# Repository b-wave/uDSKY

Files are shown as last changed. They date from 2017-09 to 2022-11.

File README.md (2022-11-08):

 
# uDSKY PROJECT
## A Physical implementaion of an Apollo AGC DSKY. 
*...with USB 2.0 Connectivity for PC simulators*

This assembly and firmware has sucessfully been used to control both
John Pultorak's Block1 Simulator vers 1.16 in C++ and Ronald Burkey's
Block 2 AGC simulators on <http://www.ibiblio.org/apollo/> 
Further, the Simulation runs great on Raspberry Pi.  I forked the 
files needed for both simulators. <https://github.com/b-wave/virtualagc> 

I mainly run it on a Rapsberry PI with the intention of embedding the Pi in this chassis. I started a 
python script that will run the software so I don't have to start the virtual AGC program.... 
now that is a *work in progress...stay tuned* 

The Teensy 3.2 used in this has a plug in board that contains a Real time clock and navigation sensors.
<https://www.pjrc.com/store/prop_shield.html>  Which will mount to the board nicely.  I also included a couple of Apollo-themed Processing PDEs in <https://github.com/b-wave/uDSKY/tree/master/uDSKY%20IMU>
that work with this board and it can mount to the uDSKY using stacking header pins. 

Why on earth did I do this project?  Ultimately, it is a clock. I intend to have a standalone
version to do navigation demonstation experiments and become a "moon clock" to track
the current position, phase, and distance to the moon - *...in real time!*

### What it is not... 
Its not to scale or even a 1:1 scale model of a DSKY.  How I arrived at the scaling was 
I took the best head-on photo of a DSKY I could find and scaled it to match the 
smallest descrete LED 7-segment *green-ish* displays I could find.
It turned out that at that scale, the Keys were  ~.75" on center, which was nice
eand almost exactly 0.75" Square. Also by happy accident the Teensey fits between the top LED
Displays. The front panel measurments was about 7.0" x 6.5" so about, but
not exactly, half the size of a real DSKY. You will see some early refernces to **mini-DSKY** 
Which is the same thing as **uDSKY**.  The whole thing sandwiches nicely together
using plexiglas plates - which I will provide laser cut patterns for - and #4 AWG hardware spacers.

The **uDSKY** assembly is remarkably sturdy and even kind of hefty too.  The keys and circuit 
boards were attached by small torx head "thread rolling" screws for plastic.  
The Torx heads allow for close proximity to components and I think a little easier to install straight.
The hardware I used were surplus and about 2 AWG, ( for a 1/16" pilot hole) and 1/8" long.  
I got them on e-bay and i don't have the link, there were 100's of them in a box for a few dollars. 
They should be easy to find. I'll update a link if I find a good supplier again. 

There are two other circuit boards I am developing.  The INDICATOR boards for the LEDs
since I used perf boards for this prototype.  The POWER REGULATOR board for stand alone
operation on 12V dc, and illuminating and controlling the VERB, NOUN, and PROG LEDs
and the keyboard backlighting. Since these are a lot of LEDs involved 12V is used for them. 
These will be controlled the same as the other LEDs using two of the non used DP signals
but thru an isolator to control 12V to theses diodes. I also have an idea to use LEDs
and some clear plexiglas to simulate the long EL strips between the three registers - 
 but this is still in the *idea phase*...but the testing is showing promise. 

uDSKY in action 9/20/19 on the 50th moonlanding, running on rPI and ran the *actual* Apollo 11 software (C055), mostly P00 for the entire duration of the flight.   This .gif was when they would have been in lunar orbit at 100hrs 38mins or so MET. 

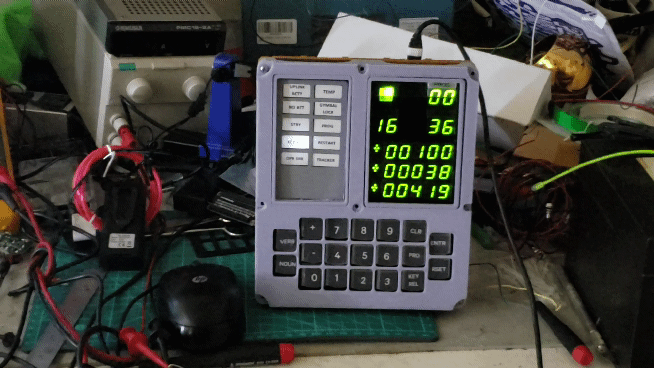
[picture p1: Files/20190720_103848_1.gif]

Running Apollo 11 CMD Module Software. 

The circuit boards are mostly attached to a 1/8" plexiglas rear plate.  The Teensey is
mounted on female pin headers on the main display board.  The Teensy actully slips thru
a recetangular hole in the rear mounting plate. 

## Displays
The displays are multiplexed with the DP segments from the first two controlling the LED INDICATORS.  Each lamp is controlled by the decimal point signals, which were not used in the original Apollo DSKY display.  This turned out to be a good parts reduction
as all the segments and Indicators can be controlle by only 3 LED controller chips.

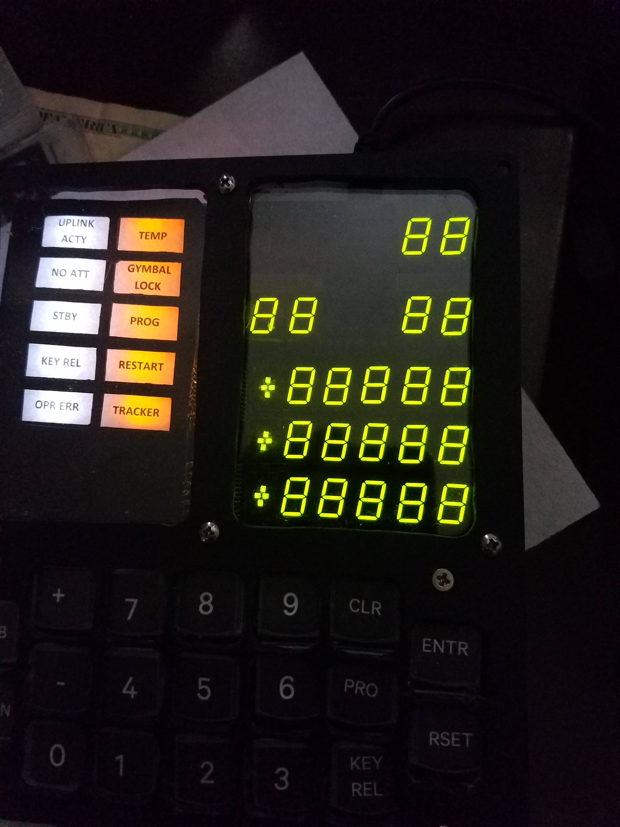
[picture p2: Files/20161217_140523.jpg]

All Displays are ON!

Only the SEGMENT G and DP are used in the first display for each of the three registors
to provide the segments for the SIGN digit.  Since there is no known compatable SIGN LED Display - i put an array of SMT LEDs on the circuit board to represent this digit.

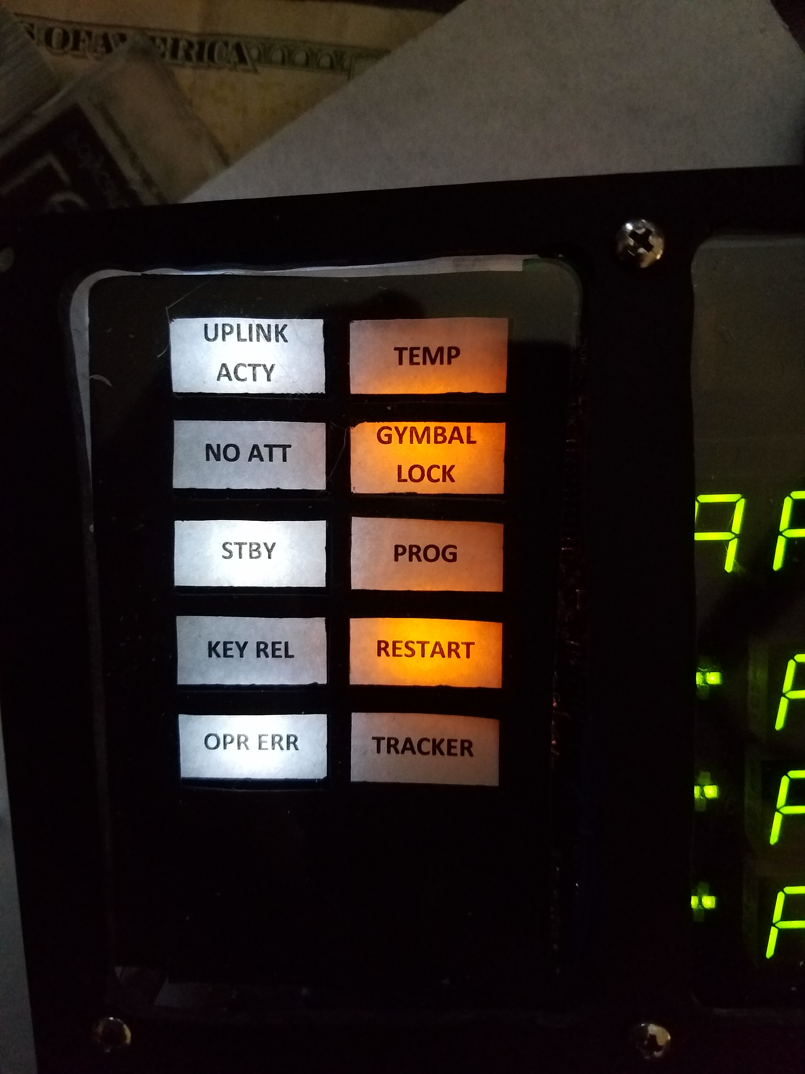
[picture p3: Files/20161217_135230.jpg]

Every Other INDIC Lamp is On.

As you can see there is still some leakage between wells of the Indicator lamps but 
this is quite usable. 

The lamps are separated with a matrix of opaque lattius.  I made the prototype with popcicle
sticks, which turned out to be a litle short.  I made a 3D printed chassis wich is way better! 
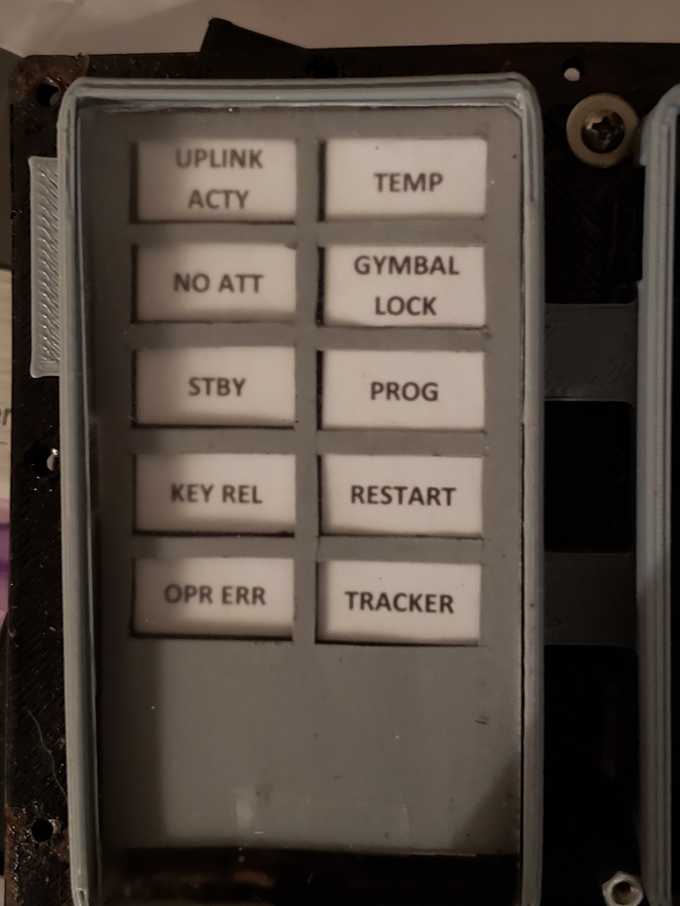
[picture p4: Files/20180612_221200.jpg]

Indicator Display Mask

In all the dispalys work fine, but later I realized that if the displays were behind a card stock printout, behind some smoked grey plexiglas they look a lot like the original Apollo DSKY EL displays.  But the LEDs were too far from the card stock to be seen.  I then developed a pair of circuit boards, one to hold the LEDs and the other provides a light mask. This brings the sign digit near to the display. 67lb. White Cover Card stock (Staples **Item 679482** to be exact).  I 

As you can see with the card stock the uDSKY is very simular to the DSKY as you cant really see the digits until they are
illuminated.  The only issue is the LED must be against the card stock for the effect to work.  I did not have the sign LED digit boards working, and the prototype had the LEDs soldered to the main board, which is too far away to be seen thru the card stock.  

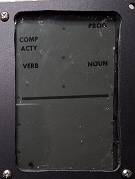
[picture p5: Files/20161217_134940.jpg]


*No digits seen With power off*

The 3D printed chasis is now on version 2.  Here are a couple of shots of the first parts.  It really started looking real, and as you can see from the .gif it is a lot better now than the original hand cut plexiglas. 

uDSKY
3D Parts

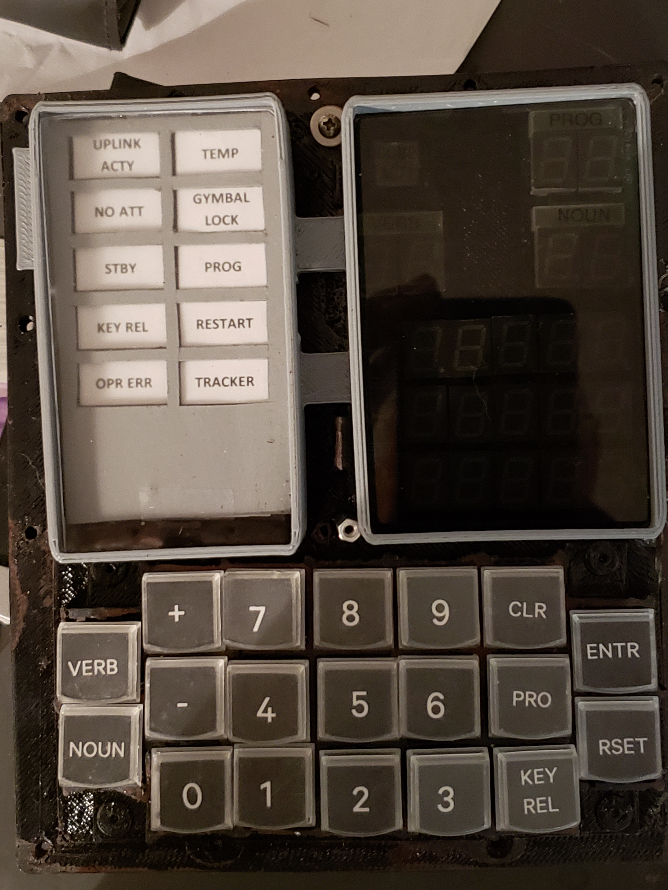
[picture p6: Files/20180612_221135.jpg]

Keys and displays added

# Apollo uDSKY's  Keys 
The Keys are Cherry MX series. These have a real nice clicky feel and best of allthey can support custom keycaps and can be illuminated! 

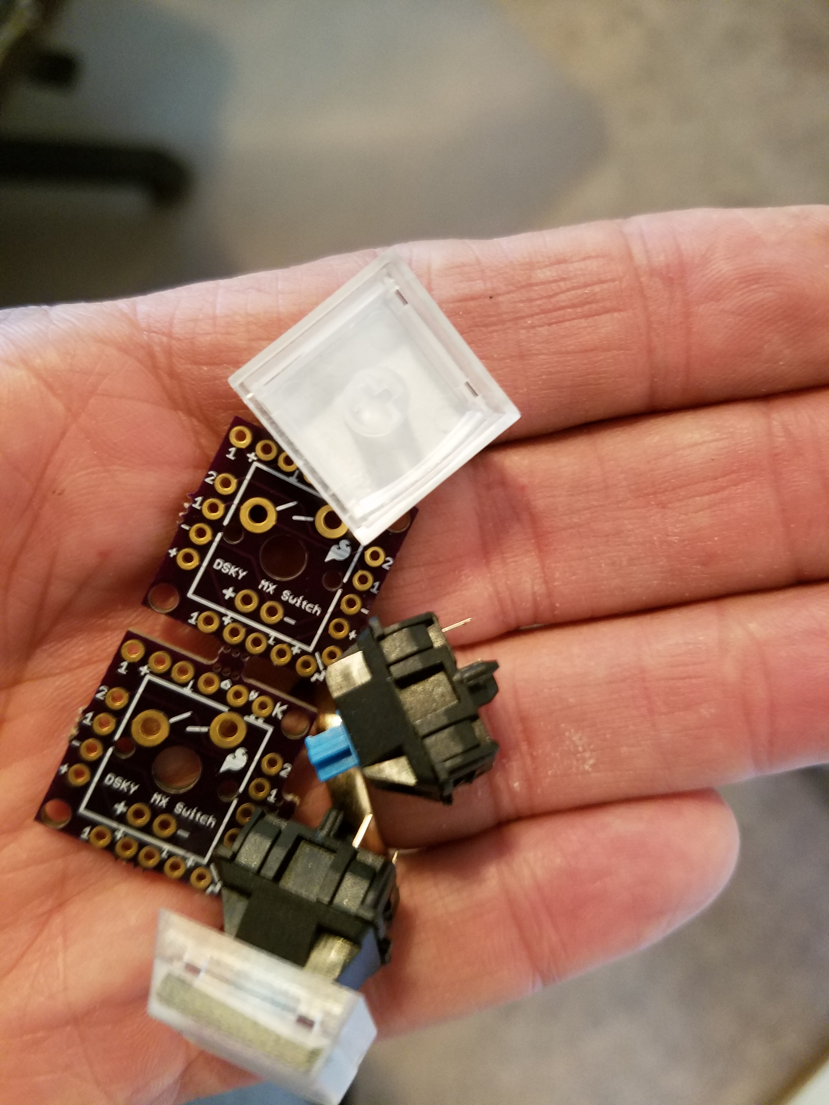
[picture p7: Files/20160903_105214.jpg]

#The key caps are from:  <http://xkeys.com/accessories/Keycaps.php> 
They are not .75" x .75 which would be ideal but they have a little curve on the bottom
which makes the laser printed labels a little tricky to line up. But it works fairly well.
You will need 19 caps (4 orders will get you 20). I got both the clear and green. I thnk the black ones
owill be opaque so they can't be illuminated. 

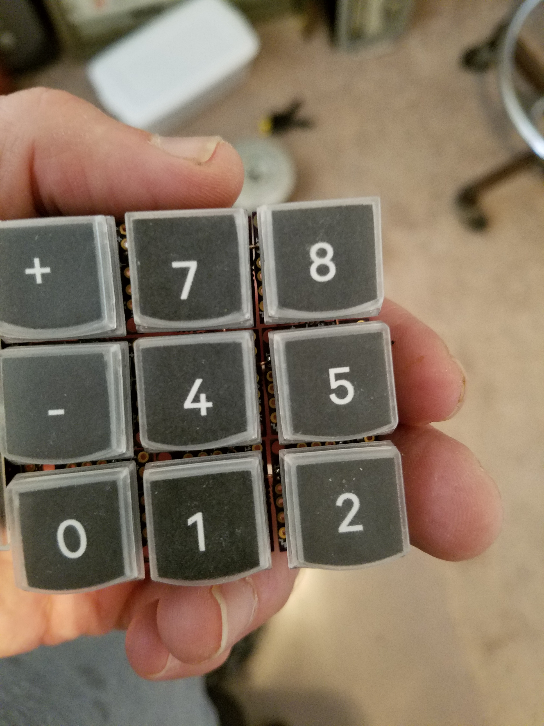
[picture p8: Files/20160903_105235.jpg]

<Keys with relegendable keycaps for cherry mx switches

The Keys are simply mounted on an *OSH Park Version*  of the SF MX breakout board. You can order them 
#or (BOB-13773) they are identical: https://www.sparkfun.com/products/13773 The next version I make may contain all 19 keys in one board.  The 1 pins are all connected for ROWS and the 2 pins are for columns.
Check out the Teensey code for the pattern and hookup. 
<https://github.com/b-wave/uDSKY/tree/master/DSKY%20Arduino%20Files>
 
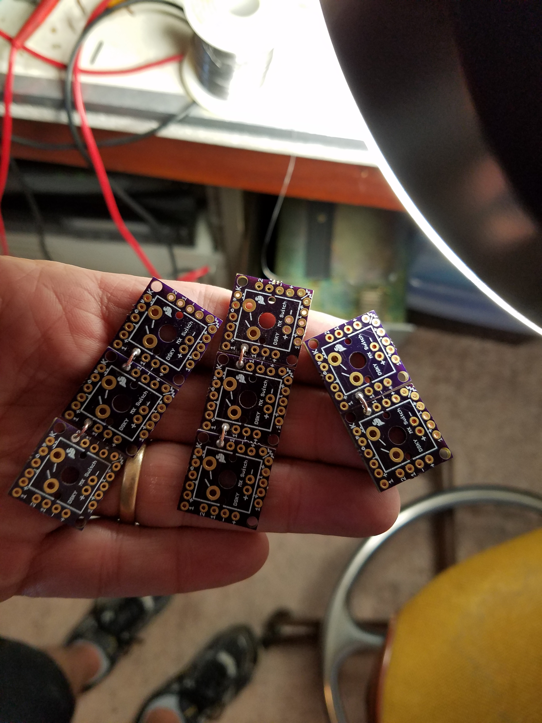
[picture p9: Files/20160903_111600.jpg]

Breakout Column connections - using the 2 Pads.

The X/Y row - column pattern is fairly self-explanitory.  The final assembly feels like holding some chain-mail armor. 
The only difficulties were to use small wire "U" shapes instead of straight from pin to pin. This makes the 
spacing of the keys line up to the holes on the base plate a little eaiser.  The second is the two columns 
on the ends don't line up anyway on one side, it helps to flip those two end keys, the pads match and the keycap will
still go on correctly. *NOTE: see the flip keys on on the right hand side of bottom view:*

uDSKY
Matrix of Keys

# Apollo uDSKY's  Registers Sign Digits
I developed a little circuit board *set* that will give a sign digit for each register.  There are actully two other ways to 
get the sign digits. First, simply put in another 7-segment display. The G segment will be (-) and the DP will represent (+) 
...*blank is octal as usual*  Second, the board has pad for SMT LEDs that form the signs.  G and DP illumiate the pairs of
LEDs but this arrangement has the distance problem, but you can still use the mask board to make the displays look better.

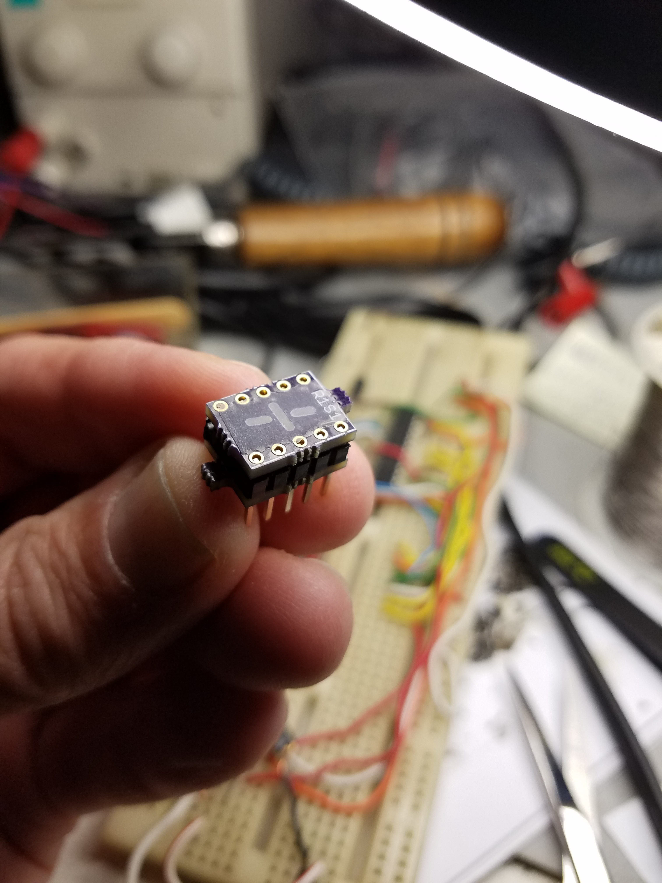
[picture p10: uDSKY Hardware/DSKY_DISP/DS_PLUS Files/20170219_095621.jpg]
uDSKY


This board will allow a pretty good substitute for the non-existent compatible LED sign digits for an **Apollo DSKY** display.  You will also need the   **DS_MASK.brd** <https://oshpark.com/shared_projects/6qTKqnak> for each display if you want the displays to be more *segment-ty?*   There are also some additional masking and diffusing techniques  that can be done to make these look really good.

##
This board set are intended to be used with a 0.39" 10-pin LED displays such as **LTS-4301G** that were used on the **uDSKY** display. 

The minus **(-)** are controlled by the standard *G - Segment* Pin **1** with 2 LEDs in series.  The **(+)** is a combination of the **"g1"**  and **"g2"** Segs *and* the vertical segments *(some times referred to as **"h"** and **"J"**)* which are connected to the **"DP"** pin **6**.  The **Common** pins are **8** and **3**.  Because both displays are *two* LEDs in series this should simplify non-MUX displays as well.

<https://www.jameco.com/z/LTS-4301G-Lite-On-Electronics-Green-7-Segment-LED-Display_2227911.html>

When selecting the SMT LEDs make sure you get them close to the brightness and color wavelength.  For example , these LED displays have: **569 nm**  (green) with an avg. intensity = **2200 µCD** @ If =10mA.

I can post some details on how to put these together.  But basically, you need to diffuse the light or the viewing angle gets critical.  A simple piece of scotch tape but hot melt glue may also work.  

The parts placement is pretty simple, The anode of the first LED connects to the respective pin.  The two LED's cathodes and anodes for each segment are connected together. The cathodes of the 2nd LEDs connect to the common pins.  If you forget one LED or get one in backwards it's like Christmas tree light strings... *no light for you!*  

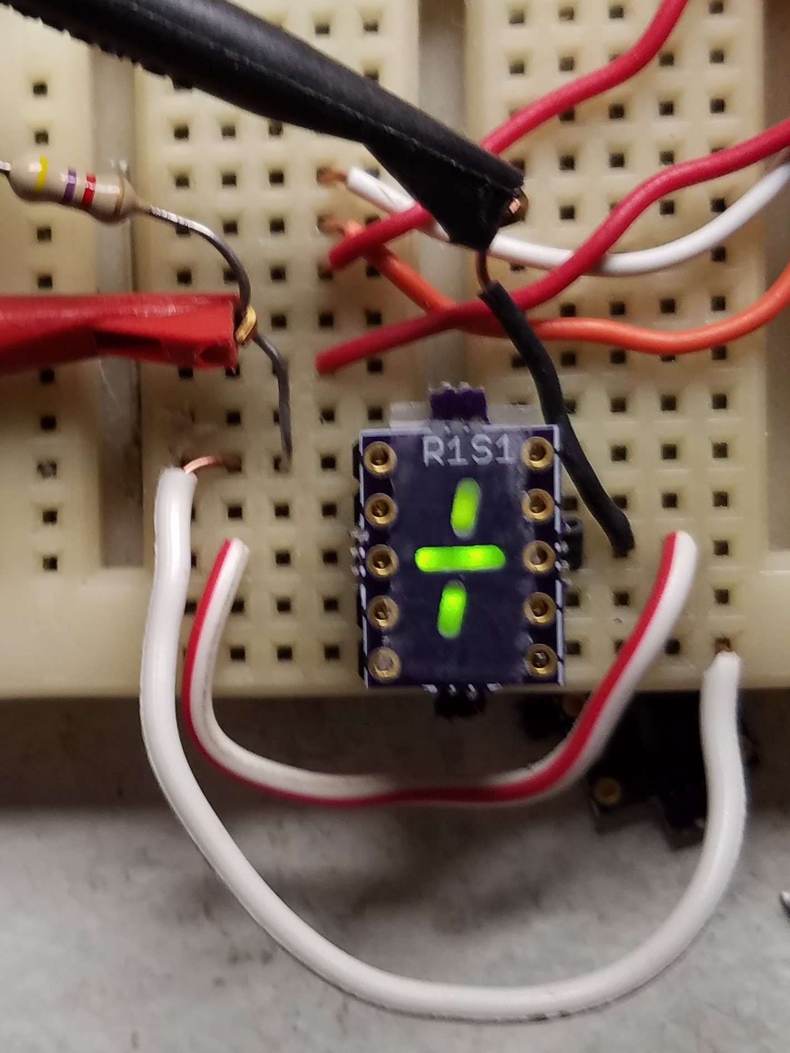
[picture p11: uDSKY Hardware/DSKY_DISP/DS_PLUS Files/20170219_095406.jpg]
uDSKY

Plus Display

A couple of baffles between the G and the vertical segments are also needed or when only (-) is displayed the other segments are still slightly visible.  I used a couple scrap pieces of black wire insulation wedged between the segments to block this.  The messy dabs of hot melt glue used to hold these in place are also visible.

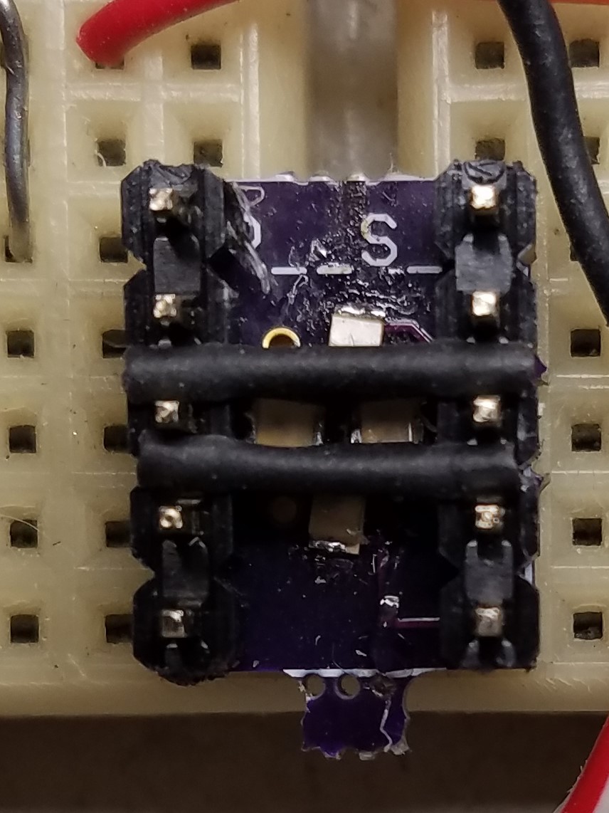
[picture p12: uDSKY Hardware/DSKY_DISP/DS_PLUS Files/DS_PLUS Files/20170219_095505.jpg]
uDSKY

Light Baffels 

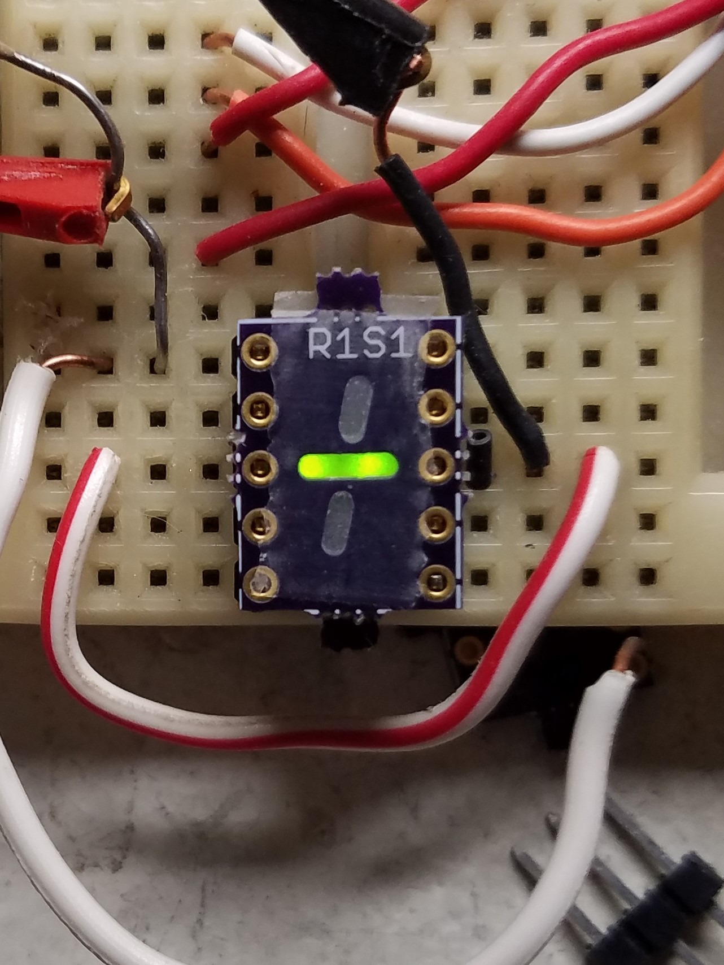
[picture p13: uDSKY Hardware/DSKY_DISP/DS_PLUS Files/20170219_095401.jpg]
uDSKY

Minus Display

Two 0.1" 5-pin headers to hold the two boards together.  Mount the header on *top* of this board (long pins go thru the board)   Then put the mask board on top of the header. The boards are separated by the plastic header. Push the pins flush to the  top **MSK_Brd** *Pins 1, 6, 8, and 3* now have to be soldered on the bottom of this board.  You can solder the mask board's pins all in place if you want to - after you verify everything is working OK of course, there are no electrical connections to any other pads.

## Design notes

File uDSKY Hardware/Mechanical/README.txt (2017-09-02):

These are the files i used to make the plates to hold the miniDSKY boards. 

I cannont say if these file will manufacture the plexi and plastic sheets 
because i just printed these out and used as a guide for drilling.

I changed the keys th the Sparkfun MX breakout board, this is .75" sq and
fits nicely into the scale. I used releagenable keys that put the printed
key caps.  The MX keys have a nice feel and can be back lit. They are attached
with small rolling plastic screws.  I will put the parts list in later.

The boards are stacked with some spacers and it sandwiches together so the
stack is fairly sturdy. 

The indicators were 1000mdc white and yellow LEDs on a perf board.

I will put the lables in PDF or another printable form.

One more board needs to be added.  I did not put mounting holes.  This is the
power supply module.  It takes in 12VDC and provides a +5V for the boards. The
12V is also run thru some opto-isolators to control 12V to the large LEDs and 
key backlights. This will be controlled thu one of the DP lines.

Three types of plastic sheets are used:

.125" Black Matt sheets (F45 I think)  these should hold paint well too

.125 50% matt white (for indicators)

The final plate is a clear plexiglas that cover the display openings and protect
the paper labels. It is a little tricky as there are some holes only part way thru.

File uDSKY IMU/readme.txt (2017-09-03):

The Teensey3 has a 9DOF shield that can be used in conjunction with the uDSKY.  
https://www.pjrc.com/store/prop_shield.html

The following files are PROCESSING sketches that can be used to visulize the
Apollo spacecraft and the FDAI indicator. This is a work in progress.  It will need
the additional hardware and to tie the DSKY firmware to these. Currently they
are just mouse controlled.  The COM Port may need to be changed to match.

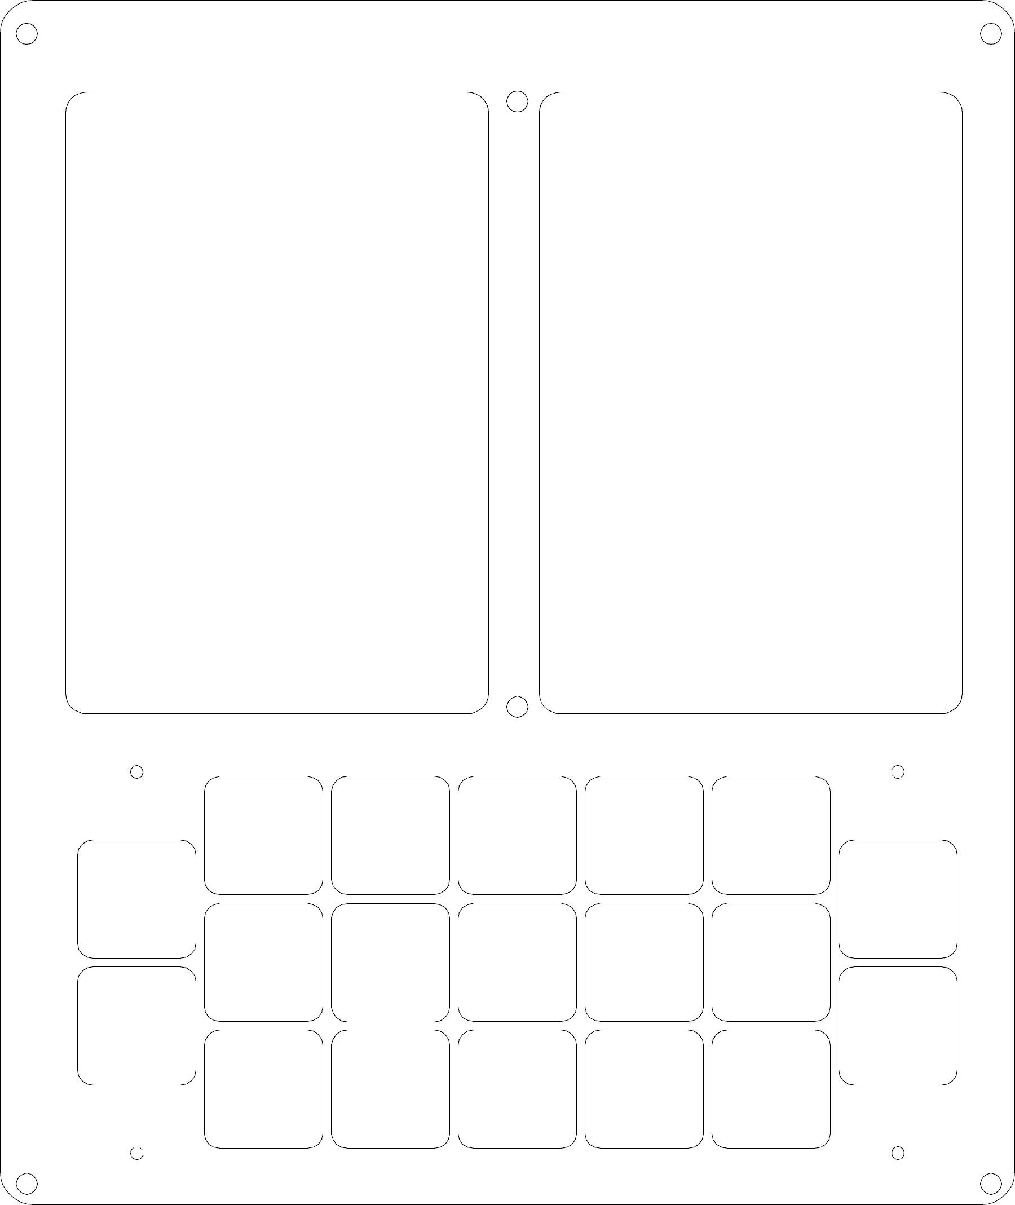
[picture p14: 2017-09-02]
uDSKY Hardware/Mechanical/miniDSKY1_Front.BMP

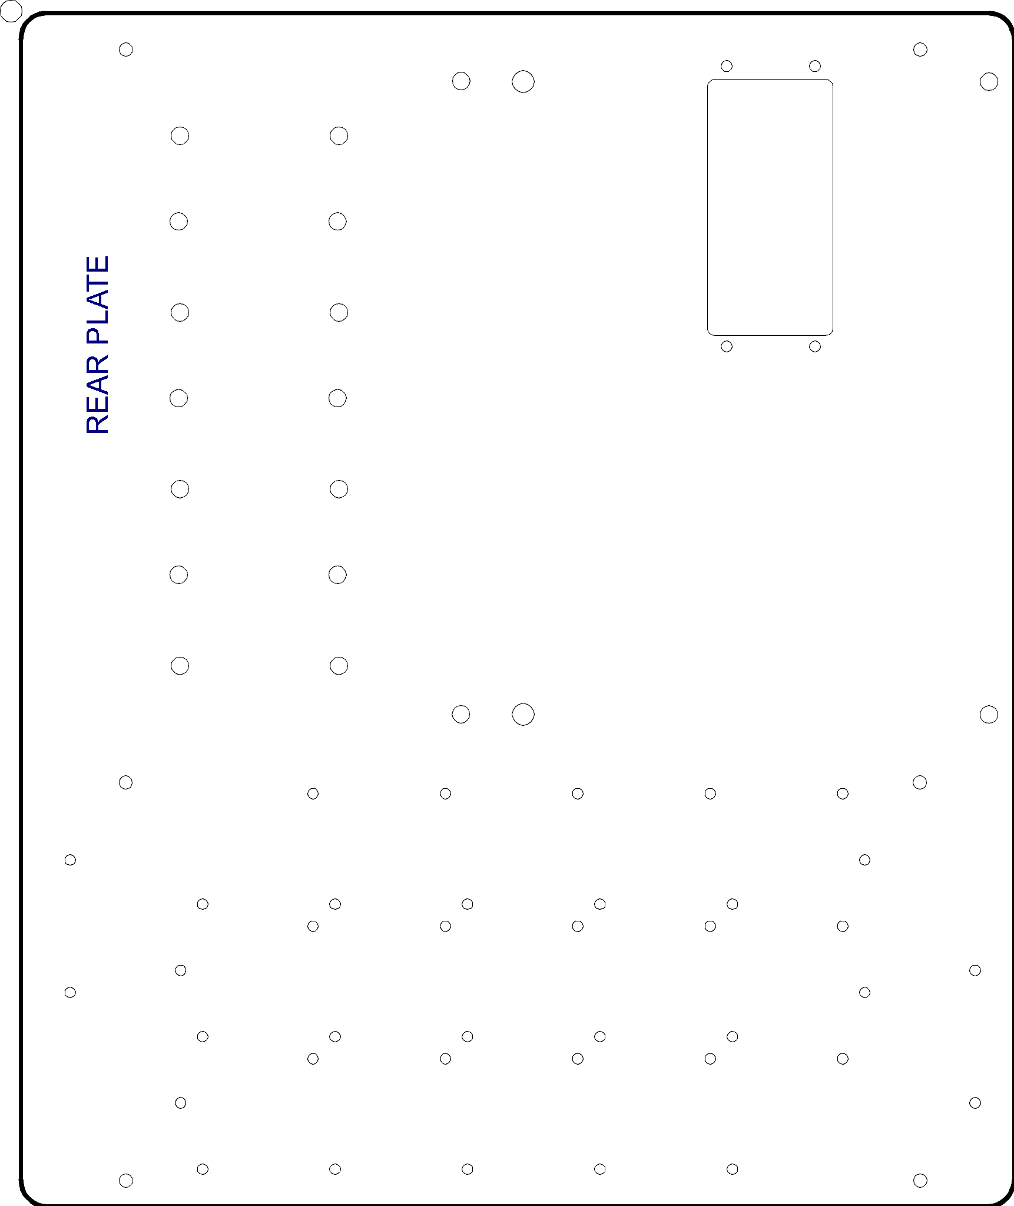
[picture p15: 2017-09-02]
uDSKY Hardware/Mechanical/miniDSKY1_PLATE.BMP

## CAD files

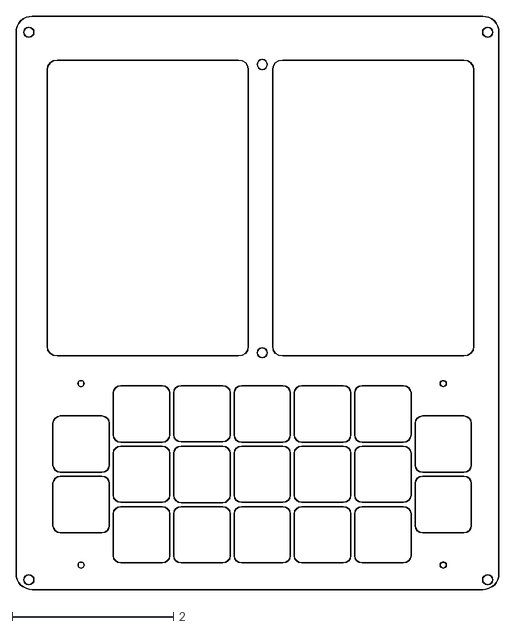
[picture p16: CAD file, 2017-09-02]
uDSKY Hardware/Mechanical/miniDSKY1_Front.DXF
6.00 x 7.12

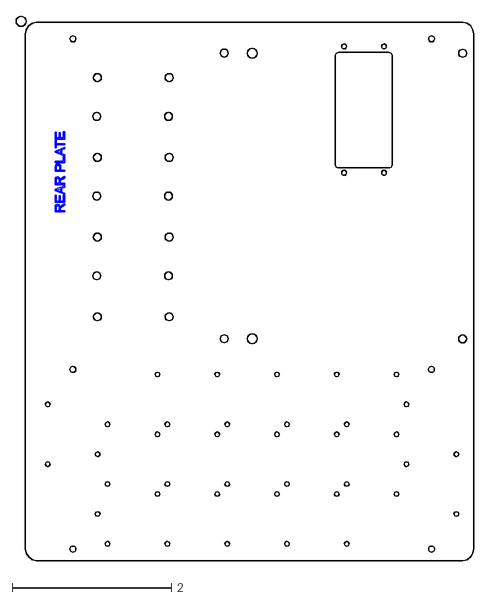
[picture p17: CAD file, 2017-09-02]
uDSKY Hardware/Mechanical/miniDSKY1_PLATE.DXF
5.74 x 6.82

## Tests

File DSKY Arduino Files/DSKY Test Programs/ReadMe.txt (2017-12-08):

Various test programs useful when constructing the miniDSKY (uDSKY) hardware.
TEST1 – Basic display test for all digits and segments
TEST2 – Basic control of displays thru debug or serial port
TEST3 – Pretty much fully working test program:
1. reads seral lines into buffer
2. parses Verb, Noun, Prog, R1, r2, r3
3. put parsed values into DSKY Displays
4. Caution (WHITE) and Warning (YELLOW) Lights control. 
5. Flash C & W Lamps
6. Flash N V Displays
7. SET/RESET COMP ACTY Lamp
8. Keypad can be as keyboard: 
    *CAUTION* writes to open screen on PC!!
    *NOTE*: Set TOOLS>USB Type>Serial+Keyboard,,

DSKYAGC4 -  This sketch was written originally to control the AGC4 software.  The software was basically the same as the original, because the Teensey looks just like a keyboard.  The output was sent on a serial port to control the displays.  These are a standard 9600 baud USB serial port. Match the port to the software. 
For writing to Verb, Noun or Prog displays: (Vxx,  Nxx, or Pxx) (it is not case sensitive) appending with a “*” causes these displays to flash at the 3:1 duty cycle.  Leaving blanks (like V<enter>) will clear the display.
   *   v10[*]/n (1 =MSB 0 =LSB '*' = Flash) 
	Example: V12<Enter> writes VERB = 12
   *   n10[*]/n
	Example: N32*<Enter> makes NOUN = 34 Flashing

PROG or Major mode, (Pxx)
   *   p10/n
p10[*]/n (1 =MSB 0 =LSB '*' = Flash) 

	Example: P00<Enter> writes PROG = 00

Registers 1, 2, or 3 ( 5 digits each Plus sign)  
   *  Rxs/n x= (1 -> 3) s= +/ - or Blank
	Example: R1+12345 <CR> Writes +12345 into R1

LED Indicators:
   *  Wnx/n[*]  (n = LED# (1 -> 5)  x = 1(on) 0(0ff) *(Flash) (Yellow LEDs)
	Example: W11<CR> Turns on TEMP Yellow lamp
   *  Cnx/n[*]  (n = LED# (1 -> 5)  x = 1(on) 0(0ff) *(Flash) (White LEDs)
	Example: C4*<CR> Flashes on KEY REL White lamp

This sketch will also work with a modified DKSY2 software on AGC SIM.

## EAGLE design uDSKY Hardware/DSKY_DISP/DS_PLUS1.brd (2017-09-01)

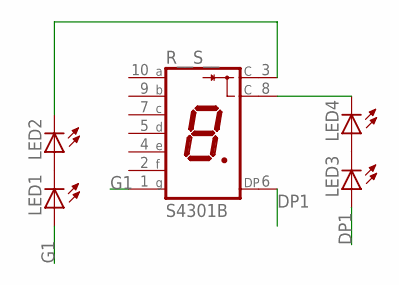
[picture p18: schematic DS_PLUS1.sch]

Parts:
LED1, LED2, LED3, LED4: LEDCHIP-LED0603; CHIP-LED0603
R__S__: S4301B

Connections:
DP1: LED3.A, R__S__.6 (DP)
G1: LED1.A, R__S__.1 (G)
unnamed: LED1.C, LED2.A
unnamed: LED3.C, LED4.A
unnamed: LED4.C, R__S__.8 (C)
unnamed: LED2.C, R__S__.3 (C)

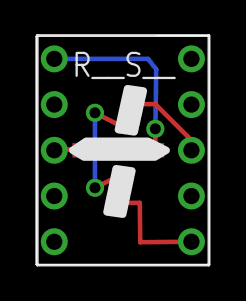
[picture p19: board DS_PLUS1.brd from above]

Board: 2 copper layers, 9.7 x 12.7 mm, 5 parts (0 on the bottom side), 6 nets.

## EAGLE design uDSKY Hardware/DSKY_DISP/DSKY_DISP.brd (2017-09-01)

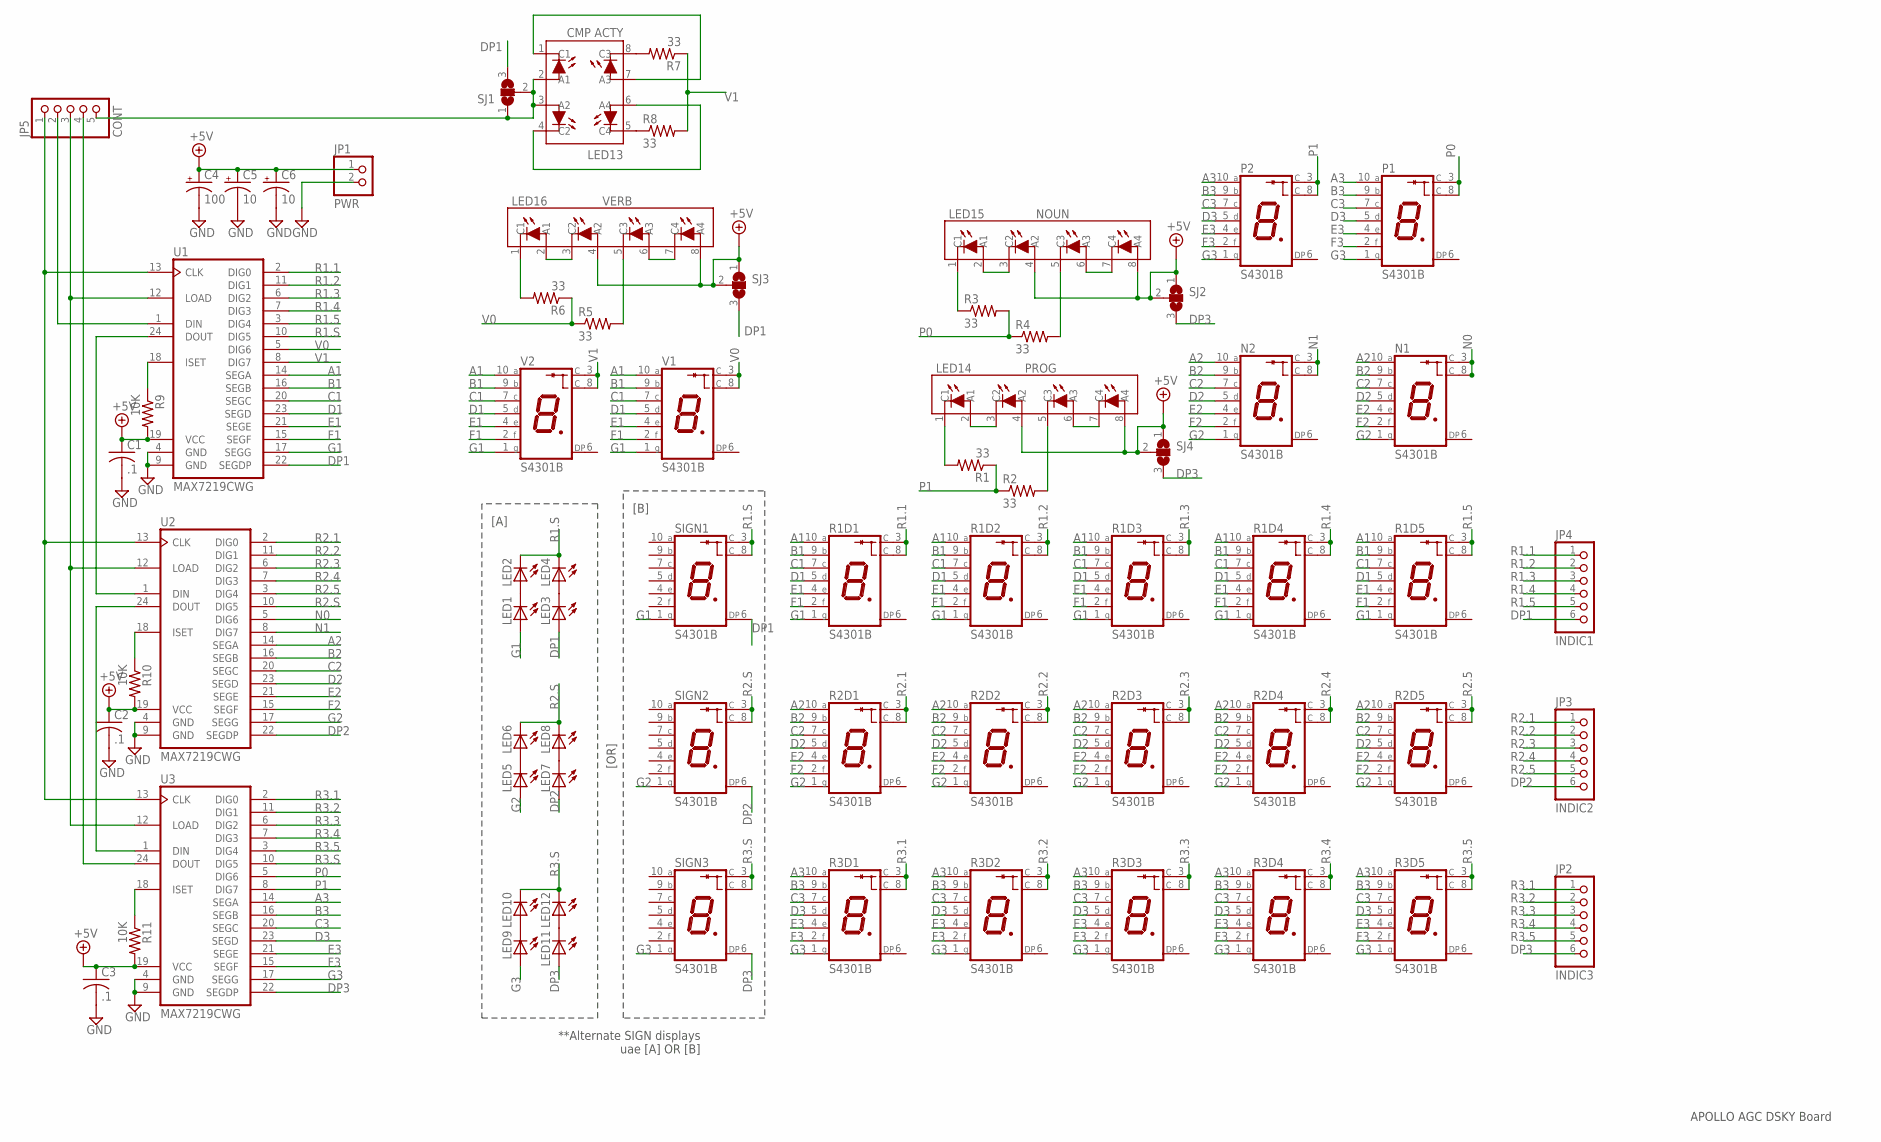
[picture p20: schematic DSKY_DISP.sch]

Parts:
C1, C2, C3: .1; C025-030X050
C4: 100; E2,5-6E
C5, C6: 10; E1,8-4
JP1: PWR; 1X02
JP2: INDIC3; 1X06
JP3: INDIC2; 1X06
JP4: INDIC1; 1X06
JP5: CONT; 1X05
LED1, LED2, LED3, LED4, LED5, LED6, LED7, LED8, LED9, LED10, LED11, LED12: LEDCHIPLED_0603; CHIPLED_0603
LED13: CMP ACTY; SOCKET-08
LED14: PROG; SIP-08
LED15: NOUN; SIP-08
LED16: VERB; SIP-08
N1, N2: S4301B
P1, P2: S4301B
R1, R2, R3, R4, R5, R6, R7, R8: 33; 0207/10
R1D1, R1D2, R1D3, R1D4, R1D5, R2D1, R2D2, R2D3, R2D4, R2D5, R3D1, R3D2, R3D3, R3D4, R3D5: S4301B
R9, R10, R11: 10K; 0207/10
SIGN1, SIGN2, SIGN3: S4301B
SJ1, SJ2, SJ3, SJ4: SJ2WW; SJ_2W
U1, U2, U3: MAX7219CWG; SO24W
V1, V2: S4301B

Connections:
+5V: C1.1, C2.1, C3.1, C4.+, C5.+, C6.+, JP1.1, LED14.4 (A2), LED14.8 (A4), LED15.4 (A2), LED15.8 (A4), LED16.4 (A2), LED16.8 (A4), R9.2, R10.2, R11.2, SJ2.1, SJ2.2, SJ3.1, SJ3.2, SJ4.1, SJ4.2, U1.19 (VCC), U2.19 (VCC), U3.19 (VCC)
A1: R1D1.10 (A), R1D2.10 (A), R1D3.10 (A), R1D4.10 (A), R1D5.10 (A), U1.14 (SEGA), V1.10 (A), V2.10 (A)
A2: N1.10 (A), N2.10 (A), R2D1.10 (A), R2D2.10 (A), R2D3.10 (A), R2D4.10 (A), R2D5.10 (A), U2.14 (SEGA)
A3: P1.10 (A), P2.10 (A), R3D1.10 (A), R3D2.10 (A), R3D3.10 (A), R3D4.10 (A), R3D5.10 (A), U3.14 (SEGA)
B1: R1D1.9 (B), R1D2.9 (B), R1D3.9 (B), R1D4.9 (B), R1D5.9 (B), U1.16 (SEGB), V1.9 (B), V2.9 (B)
B2: N1.9 (B), N2.9 (B), R2D1.9 (B), R2D2.9 (B), R2D3.9 (B), R2D4.9 (B), R2D5.9 (B), U2.16 (SEGB)
B3: P1.9 (B), P2.9 (B), R3D1.9 (B), R3D2.9 (B), R3D3.9 (B), R3D4.9 (B), R3D5.9 (B), U3.16 (SEGB)
C1: R1D1.7 (C), R1D2.7 (C), R1D3.7 (C), R1D4.7 (C), R1D5.7 (C), U1.20 (SEGC), V1.7 (C), V2.7 (C)
C2: N1.7 (C), N2.7 (C), R2D1.7 (C), R2D2.7 (C), R2D3.7 (C), R2D4.7 (C), R2D5.7 (C), U2.20 (SEGC)
C3: P1.7 (C), P2.7 (C), R3D1.7 (C), R3D2.7 (C), R3D3.7 (C), R3D4.7 (C), R3D5.7 (C), U3.20 (SEGC)
D1: R1D1.5 (D), R1D2.5 (D), R1D3.5 (D), R1D4.5 (D), R1D5.5 (D), U1.23 (SEGD), V1.5 (D), V2.5 (D)
D2: N1.5 (D), N2.5 (D), R2D1.5 (D), R2D2.5 (D), R2D3.5 (D), R2D4.5 (D), R2D5.5 (D), U2.23 (SEGD)
D3: P1.5 (D), P2.5 (D), R3D1.5 (D), R3D2.5 (D), R3D3.5 (D), R3D4.5 (D), R3D5.5 (D), U3.23 (SEGD)
DP1: JP4.6, LED3.A, SIGN1.6 (DP), SJ1.3, SJ3.3, U1.22 (SEGDP)
DP2: JP3.6, LED7.A, SIGN2.6 (DP), U2.22 (SEGDP)
DP3: JP2.6, LED11.A, SIGN3.6 (DP), SJ2.3, SJ4.3, U3.22 (SEGDP)
E1: R1D1.4 (E), R1D2.4 (E), R1D3.4 (E), R1D4.4 (E), R1D5.4 (E), U1.21 (SEGE), V1.4 (E), V2.4 (E)
E2: N1.4 (E), N2.4 (E), R2D1.4 (E), R2D2.4 (E), R2D3.4 (E), R2D4.4 (E), R2D5.4 (E), U2.21 (SEGE)
E3: P1.4 (E), P2.4 (E), R3D1.4 (E), R3D2.4 (E), R3D3.4 (E), R3D4.4 (E), R3D5.4 (E), U3.21 (SEGE)
F1: R1D1.2 (F), R1D2.2 (F), R1D3.2 (F), R1D4.2 (F), R1D5.2 (F), U1.15 (SEGF), V1.2 (F), V2.2 (F)
F2: N1.2 (F), N2.2 (F), R2D1.2 (F), R2D2.2 (F), R2D3.2 (F), R2D4.2 (F), R2D5.2 (F), U2.15 (SEGF)
F3: P1.2 (F), P2.2 (F), R3D1.2 (F), R3D2.2 (F), R3D3.2 (F), R3D4.2 (F), R3D5.2 (F), U3.15 (SEGF)
G1: LED1.A, R1D1.1 (G), R1D2.1 (G), R1D3.1 (G), R1D4.1 (G), R1D5.1 (G), SIGN1.1 (G), U1.17 (SEGG), V1.1 (G), V2.1 (G)
G2: LED5.A, N1.1 (G), N2.1 (G), R2D1.1 (G), R2D2.1 (G), R2D3.1 (G), R2D4.1 (G), R2D5.1 (G), SIGN2.1 (G), U2.17 (SEGG)
G3: LED9.A, P1.1 (G), P2.1 (G), R3D1.1 (G), R3D2.1 (G), R3D3.1 (G), R3D4.1 (G), R3D5.1 (G), SIGN3.1 (G), U3.17 (SEGG)
GND: C1.2, C2.2, C3.2, C4.-, C5.-, C6.-, JP1.2, U1.4 (GND), U1.9 (GND), U2.4 (GND), U2.9 (GND), U3.4 (GND), U3.9 (GND)
N0: N1.3 (C), N1.8 (C), U2.5 (DIG6)
N1: N2.3 (C), N2.8 (C), U2.8 (DIG7)
unnamed: LED1.C, LED2.A
unnamed: LED3.C, LED4.A
unnamed: LED5.C, LED6.A
unnamed: LED7.C, LED8.A
unnamed: LED11.C, LED12.A
unnamed: LED9.C, LED10.A
unnamed: LED14.6 (A3), LED14.7 (C4)
unnamed: LED14.2 (A1), LED14.3 (C2)
unnamed: LED15.6 (A3), LED15.7 (C4)
unnamed: LED15.2 (A1), LED15.3 (C2)
unnamed: LED16.6 (A3), LED16.7 (C4)
unnamed: LED16.2 (A1), LED16.3 (C2)
unnamed: LED13.1 (C1), LED13.7 (A3)
unnamed: LED13.4 (C2), LED13.6 (A4)
unnamed: LED14.1 (C1), R1.2
unnamed: LED14.5 (C3), R2.2
unnamed: LED13.8 (C3), R7.2
unnamed: LED15.1 (C1), R3.1
unnamed: LED15.5 (C3), R4.2
unnamed: LED13.5 (C4), R8.1
unnamed: LED16.5 (C3), R5.2
unnamed: LED16.1 (C1), R6.2
unnamed: JP5.2, U1.1 (DIN)
unnamed: U1.24 (DOUT), U2.1 (DIN)
unnamed: U2.24 (DOUT), U3.1 (DIN)
unnamed: JP5.3, U1.12 (LOAD), U2.12 (LOAD), U3.12 (LOAD)
unnamed: JP5.1, U1.13 (CLK), U2.13 (CLK), U3.13 (CLK)
unnamed: JP5.4, U3.24 (DOUT)
unnamed: R9.1, U1.18 (ISET)
unnamed: R10.1, U2.18 (ISET)
unnamed: R11.1, U3.18 (ISET)
unnamed: JP5.5, LED13.2 (A1), LED13.3 (A2), SJ1.1, SJ1.2
P0: P1.3 (C), P1.8 (C), R3.2, R4.1, U3.5 (DIG6)
P1: P2.3 (C), P2.8 (C), R1.1, R2.1, U3.8 (DIG7)
R1.1: JP4.1, R1D1.3 (C), R1D1.8 (C), U1.2 (DIG0)
R1.2: JP4.2, R1D2.3 (C), R1D2.8 (C), U1.11 (DIG1)
R1.3: JP4.3, R1D3.3 (C), R1D3.8 (C), U1.6 (DIG2)
R1.4: JP4.4, R1D4.3 (C), R1D4.8 (C), U1.7 (DIG3)
R1.5: JP4.5, R1D5.3 (C), R1D5.8 (C), U1.3 (DIG4)
R1.S: LED2.C, LED4.C, SIGN1.3 (C), SIGN1.8 (C), U1.10 (DIG5)
R2.1: JP3.1, R2D1.3 (C), R2D1.8 (C), U2.2 (DIG0)
R2.2: JP3.2, R2D2.3 (C), R2D2.8 (C), U2.11 (DIG1)
R2.3: JP3.3, R2D3.3 (C), R2D3.8 (C), U2.6 (DIG2)
R2.4: JP3.4, R2D4.3 (C), R2D4.8 (C), U2.7 (DIG3)
R2.5: JP3.5, R2D5.3 (C), R2D5.8 (C), U2.3 (DIG4)
R2.S: LED6.C, LED8.C, SIGN2.3 (C), SIGN2.8 (C), U2.10 (DIG5)
R3.1: JP2.1, R3D1.3 (C), R3D1.8 (C), U3.2 (DIG0)
R3.2: JP2.2, R3D2.3 (C), R3D2.8 (C), U3.11 (DIG1)
R3.3: JP2.3, R3D3.3 (C), R3D3.8 (C), U3.6 (DIG2)
R3.4: JP2.4, R3D4.3 (C), R3D4.8 (C), U3.7 (DIG3)
R3.5: JP2.5, R3D5.3 (C), R3D5.8 (C), U3.3 (DIG4)
R3.S: LED10.C, LED12.C, SIGN3.3 (C), SIGN3.8 (C), U3.10 (DIG5)
V0: R5.1, R6.1, U1.5 (DIG6), V1.3 (C), V1.8 (C)
V1: R7.1, R8.2, U1.8 (DIG7), V2.3 (C), V2.8 (C)

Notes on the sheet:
[OR]
**Alternate SIGN displays uae [A] OR [B]
[A]
[B]
APOLLO AGC DSKY Board

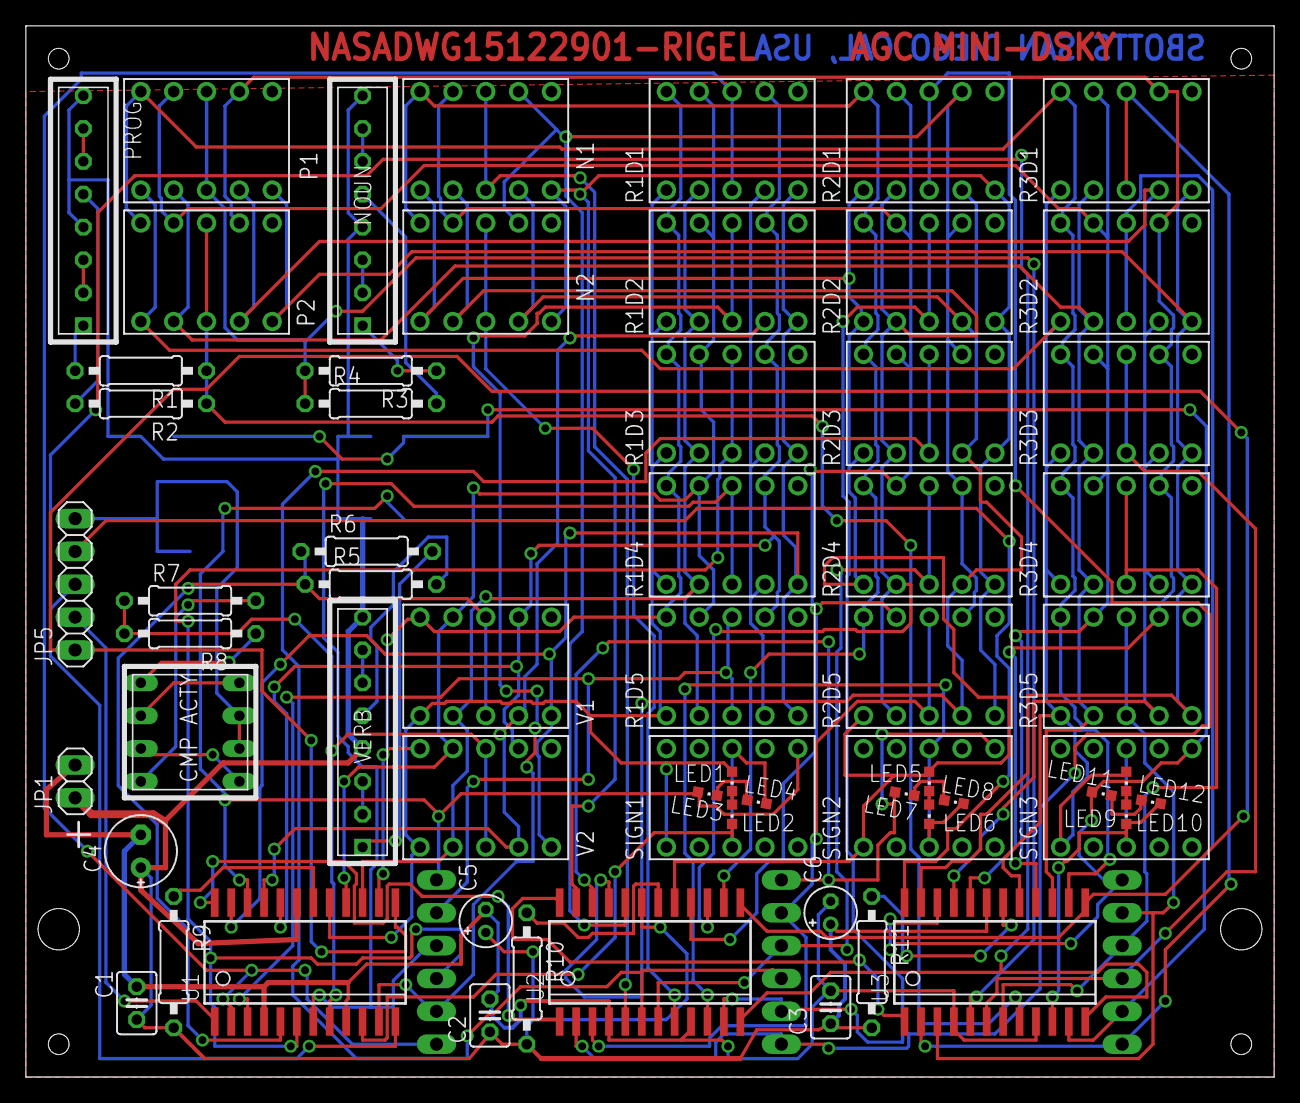
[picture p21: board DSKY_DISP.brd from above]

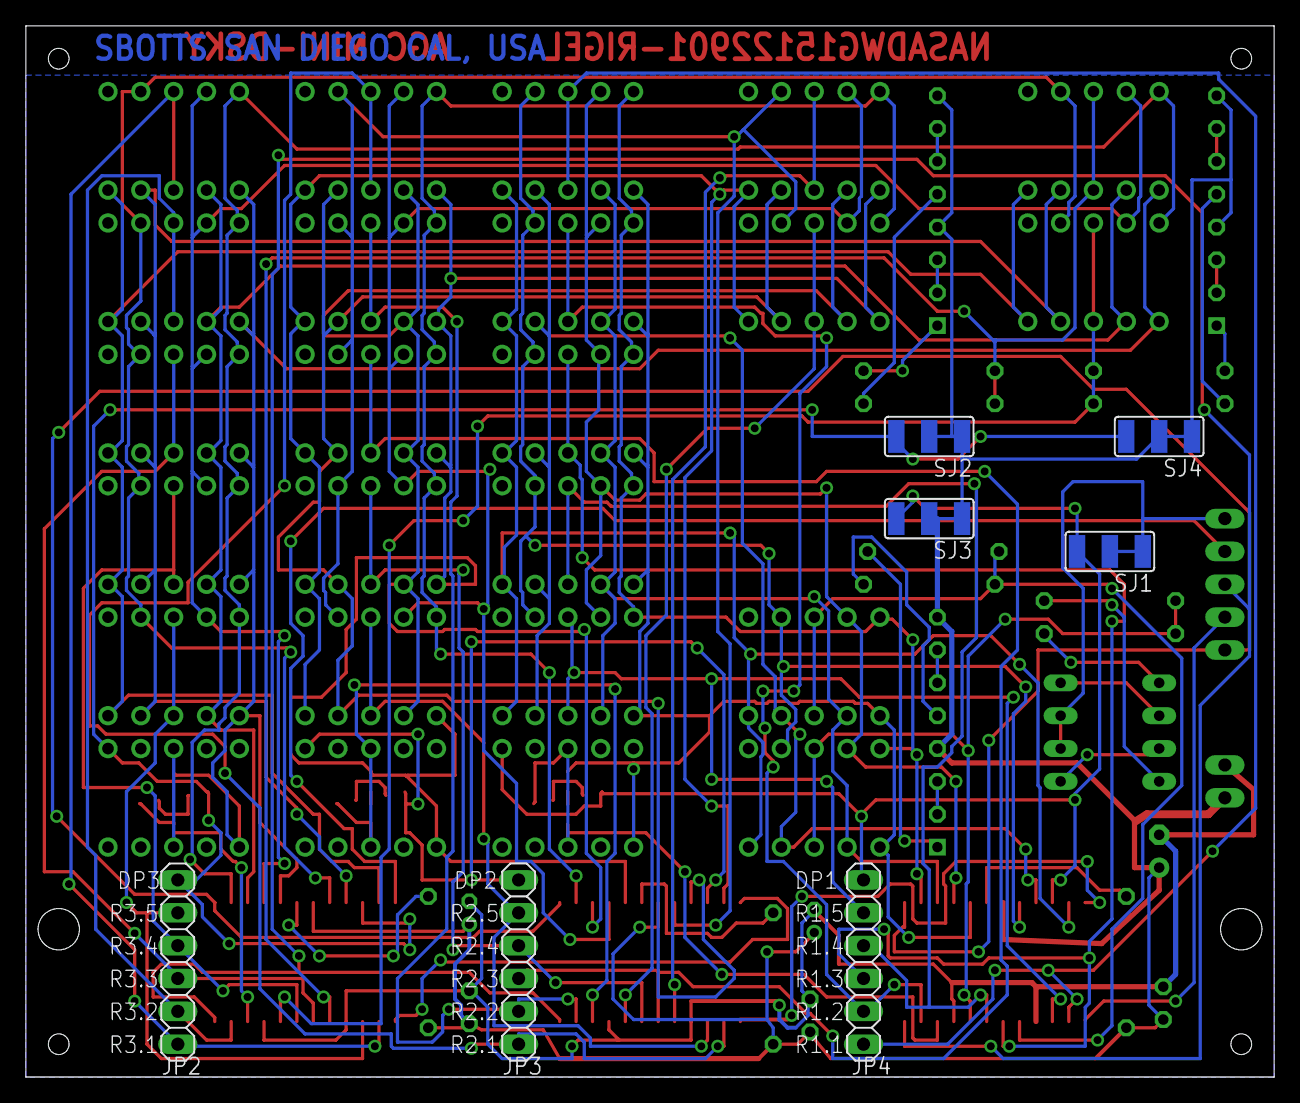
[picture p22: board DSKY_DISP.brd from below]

Board: 2 copper layers, 96.5 x 81.3 mm, 69 parts (7 on the bottom side), 82 nets.

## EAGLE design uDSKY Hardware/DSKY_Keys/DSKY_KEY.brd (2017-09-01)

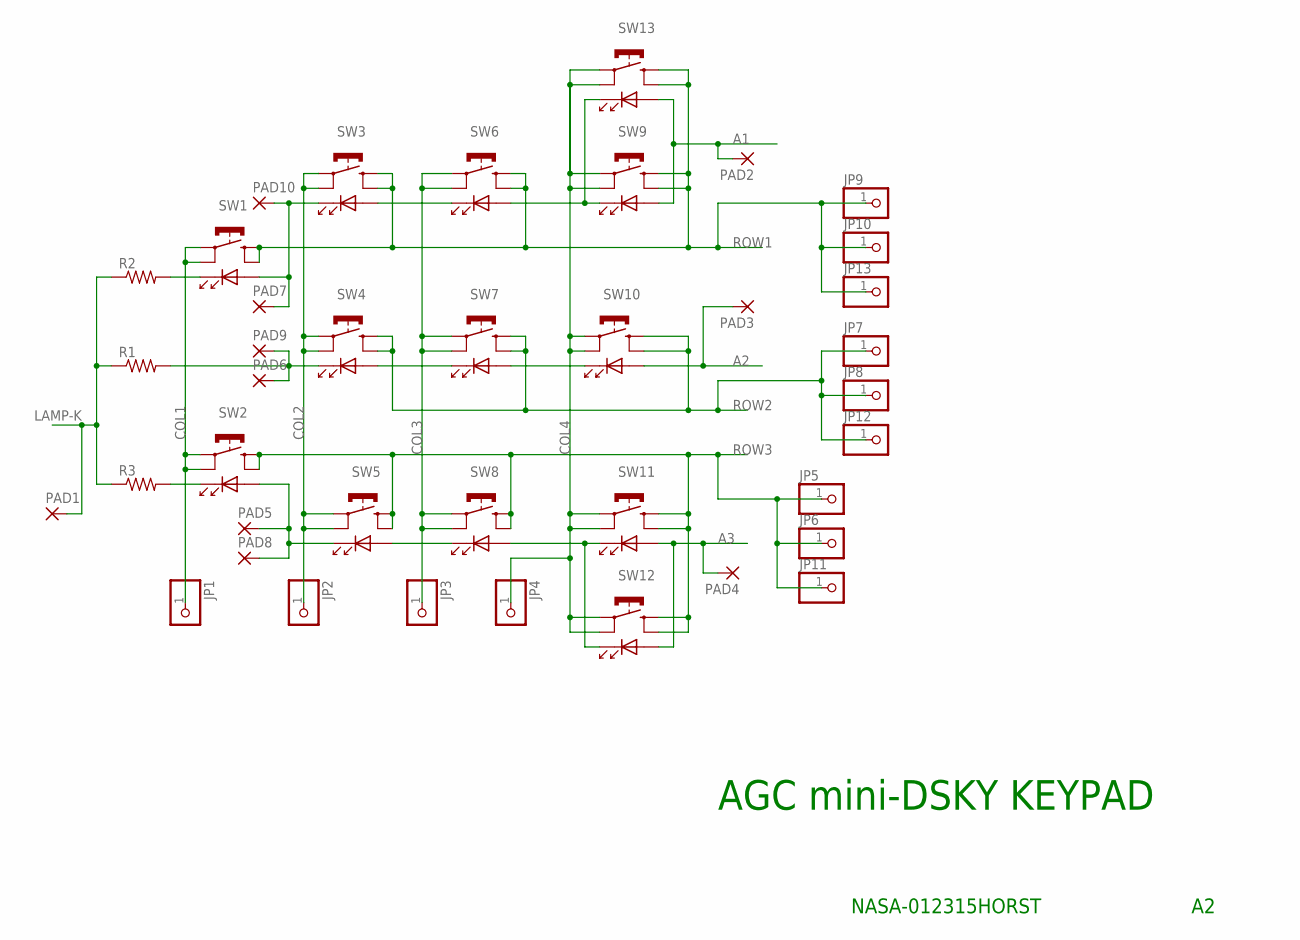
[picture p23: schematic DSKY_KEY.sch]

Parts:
JP1, JP2, JP3, JP4, JP5, JP6, JP7, JP8, JP9, JP10, JP11, JP12, JP13: PINHD-1X1; 1X01
PAD1: 2,54/0,8
PAD2, PAD3, PAD4, PAD5, PAD6, PAD7, PAD8, PAD9, PAD10: 1,6/0,8
R1, R2, R3: R-US_0204/7; 0204/7
SW1, SW2, SW3, SW4, SW5, SW6, SW7, SW8, SW9, SW10, SW11, SW12, SW13: B3E-1100; B3E-11XX

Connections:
A1: PAD2.1, SW9.P$5 (A), SW13.P$5 (A)
A2: PAD3.1, SW10.P$5 (A)
A3: PAD4.1, SW11.P$5 (A), SW12.P$5 (A)
COL1: JP1.1, SW1.P$1, SW1.P$2 (P1), SW2.P$1, SW2.P$2 (P1)
COL2: JP2.1, SW3.P$1, SW3.P$2 (P1), SW4.P$1, SW4.P$2 (P1), SW5.P$1, SW5.P$2 (P1)
COL3: JP3.1, SW6.P$1, SW6.P$2 (P1), SW7.P$1, SW7.P$2 (P1), SW8.P$1, SW8.P$2 (P1)
COL4: JP4.1, SW9.P$1, SW9.P$2 (P1), SW10.P$1, SW10.P$2 (P1), SW11.P$1, SW11.P$2 (P1), SW12.P$1, SW12.P$2 (P1), SW13.P$1, SW13.P$2 (P1)
LAMP-K: PAD1.1, R1.1, R2.1, R3.1
unnamed: R2.2, SW1.P$6 (K)
unnamed: R3.2, SW2.P$6 (K)
unnamed: PAD6.1, PAD9.1, R1.2, SW4.P$6 (K)
unnamed: SW8.P$5 (A), SW11.P$6 (K), SW12.P$6 (K)
unnamed: SW6.P$5 (A), SW9.P$6 (K), SW13.P$6 (K)
unnamed: SW5.P$5 (A), SW8.P$6 (K)
unnamed: PAD5.1, PAD8.1, SW2.P$5 (A), SW5.P$6 (K)
unnamed: SW7.P$5 (A), SW10.P$6 (K)
unnamed: SW4.P$5 (A), SW7.P$6 (K)
unnamed: PAD7.1, PAD10.1, SW1.P$5 (A), SW3.P$6 (K)
unnamed: SW3.P$5 (A), SW6.P$6 (K)
ROW1: JP9.1, JP10.1, JP13.1, SW1.P$3 (S), SW1.P$4 (S1), SW3.P$3 (S), SW3.P$4 (S1), SW6.P$3 (S), SW6.P$4 (S1), SW9.P$3 (S), SW9.P$4 (S1), SW13.P$3 (S), SW13.P$4 (S1)
ROW2: JP7.1, JP8.1, JP12.1, SW4.P$3 (S), SW4.P$4 (S1), SW7.P$3 (S), SW7.P$4 (S1), SW10.P$3 (S), SW10.P$4 (S1)
ROW3: JP5.1, JP6.1, JP11.1, SW2.P$3 (S), SW2.P$4 (S1), SW5.P$3 (S), SW5.P$4 (S1), SW8.P$3 (S), SW8.P$4 (S1), SW11.P$3 (S), SW11.P$4 (S1), SW12.P$3 (S), SW12.P$4 (S1)

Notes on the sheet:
AGC mini-DSKY KEYPAD
NASA-012315HORST

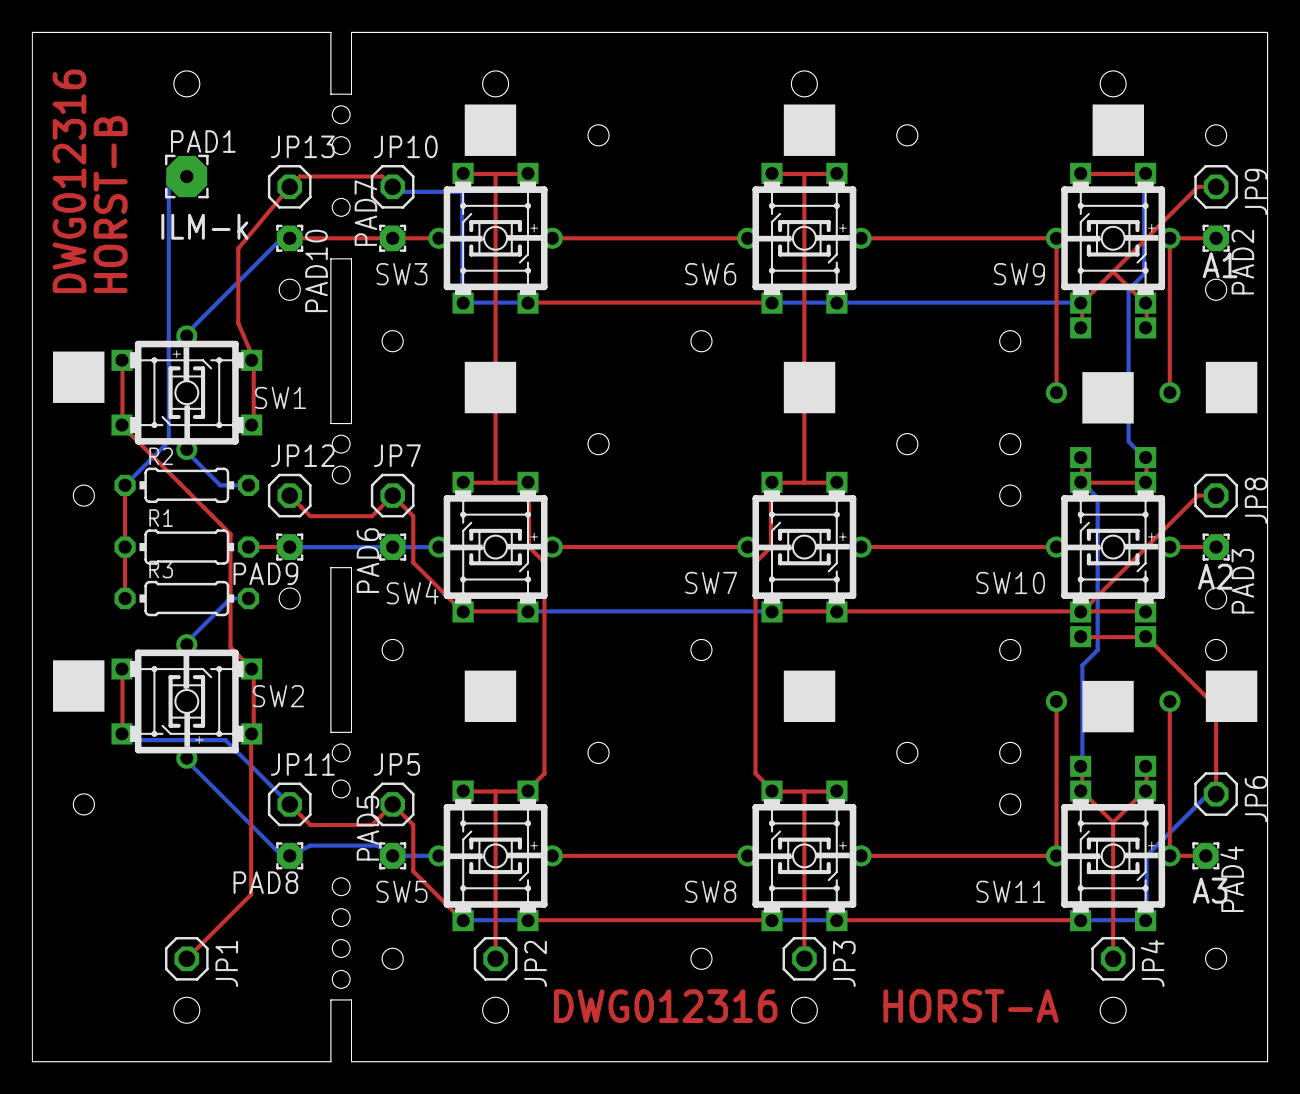
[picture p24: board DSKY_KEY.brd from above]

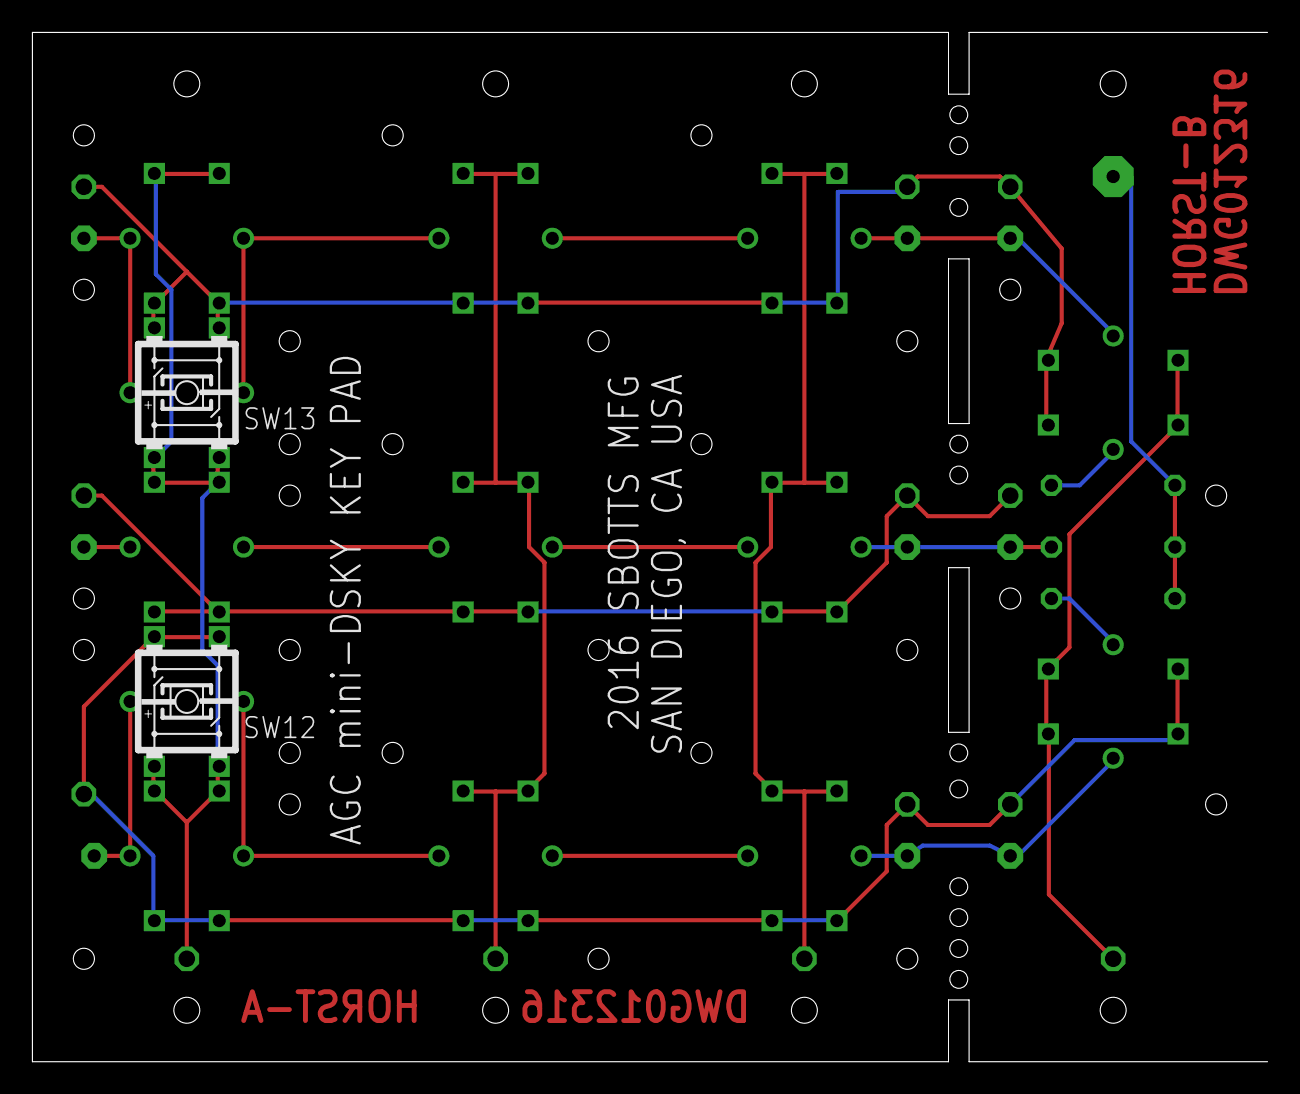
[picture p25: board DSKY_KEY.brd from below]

Board: 2 copper layers, 76.2 x 63.5 mm, 39 parts (2 on the bottom side), 22 nets.

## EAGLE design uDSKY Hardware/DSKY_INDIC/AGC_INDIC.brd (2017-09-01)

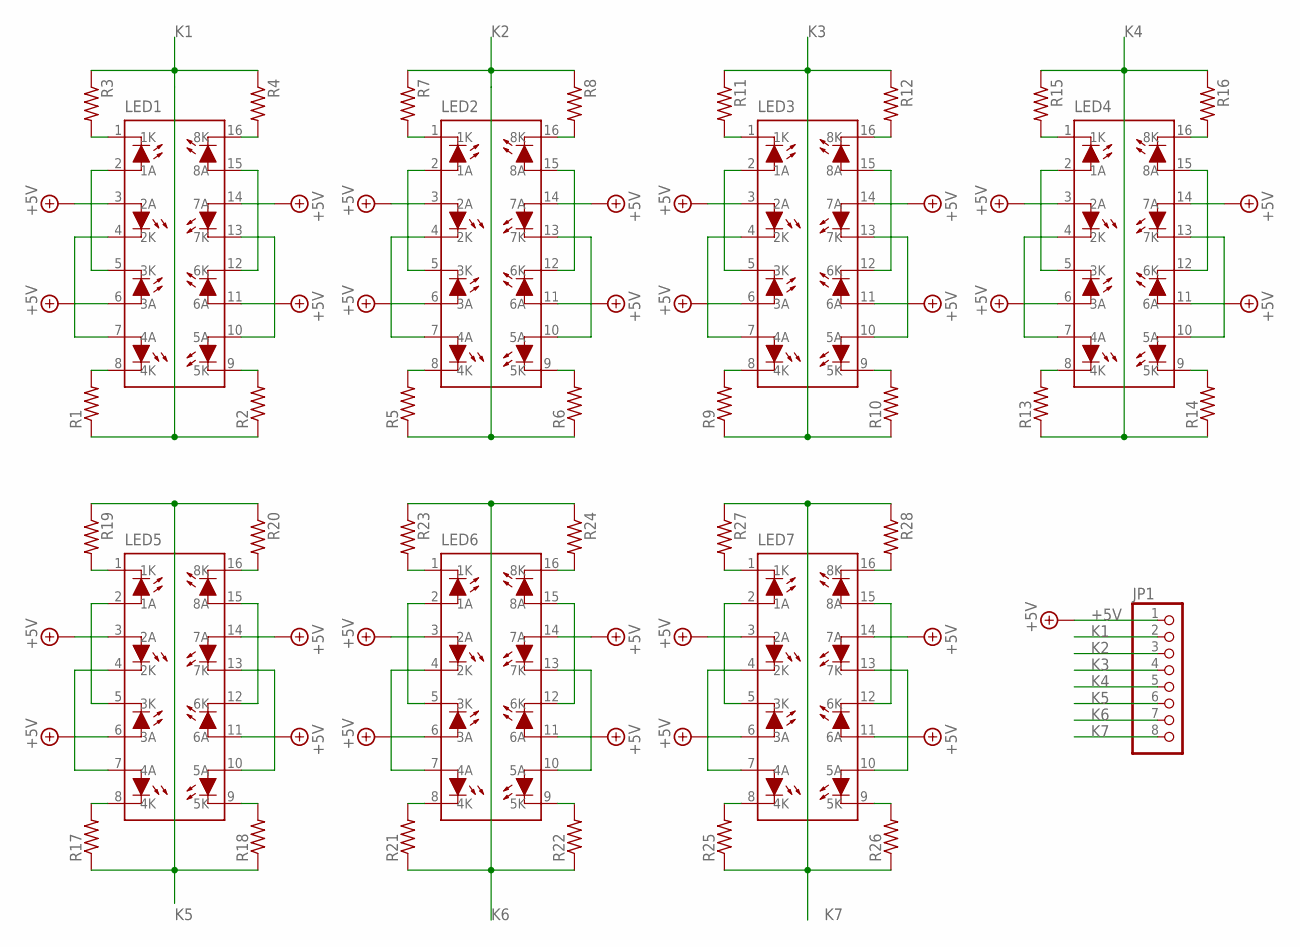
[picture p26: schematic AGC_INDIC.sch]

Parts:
JP1: PINHD-1X8; 1X08
LED1, LED2, LED3, LED4, LED5, LED6, LED7: HCLP-E; E100-16
R1, R2, R3, R4, R5, R6, R7, R8, R9, R10, R11, R12, R13, R14, R15, R16, R17, R18, R19, R20, R21, R22, R23, R24, R25, R26, R27, R28: R-US_0204/5; 0204/5

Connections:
+5V: JP1.1, LED1.3 (2A), LED1.6 (3A), LED1.11 (6A), LED1.14 (7A), LED2.3 (2A), LED2.6 (3A), LED2.11 (6A), LED2.14 (7A), LED3.3 (2A), LED3.6 (3A), LED3.11 (6A), LED3.14 (7A), LED4.3 (2A), LED4.6 (3A), LED4.11 (6A), LED4.14 (7A), LED5.3 (2A), LED5.6 (3A), LED5.11 (6A), LED5.14 (7A), LED6.3 (2A), LED6.6 (3A), LED6.11 (6A), LED6.14 (7A), LED7.3 (2A), LED7.6 (3A), LED7.11 (6A), LED7.14 (7A)
K1: JP1.2, R1.1, R2.1, R3.1, R4.1
K2: JP1.3, R5.1, R6.1, R7.1, R8.1
K3: JP1.4, R9.1, R10.1, R11.1, R12.1
K4: JP1.5, R13.1, R14.1, R15.1, R16.1
K5: JP1.6, R17.1, R18.1, R19.1, R20.1
K6: JP1.7, R21.1, R22.1, R23.1, R24.1
K7: JP1.8, R25.1, R26.1, R27.1, R28.1
unnamed: LED1.2 (1A), LED1.5 (3K)
unnamed: LED1.4 (2K), LED1.7 (4A)
unnamed: LED1.12 (6K), LED1.15 (8A)
unnamed: LED1.10 (5A), LED1.13 (7K)
unnamed: LED1.8 (4K), R1.2
unnamed: LED1.9 (5K), R2.2
unnamed: LED1.1 (1K), R3.2
unnamed: LED1.16 (8K), R4.2
unnamed: LED2.2 (1A), LED2.5 (3K)
unnamed: LED2.4 (2K), LED2.7 (4A)
unnamed: LED2.12 (6K), LED2.15 (8A)
unnamed: LED2.10 (5A), LED2.13 (7K)
unnamed: LED2.8 (4K), R5.2
unnamed: LED2.9 (5K), R6.2
unnamed: LED2.1 (1K), R7.2
unnamed: LED2.16 (8K), R8.2
unnamed: LED3.2 (1A), LED3.5 (3K)
unnamed: LED3.4 (2K), LED3.7 (4A)
unnamed: LED3.12 (6K), LED3.15 (8A)
unnamed: LED3.10 (5A), LED3.13 (7K)
unnamed: LED3.8 (4K), R9.2
unnamed: LED3.9 (5K), R10.2
unnamed: LED3.1 (1K), R11.2
unnamed: LED3.16 (8K), R12.2
unnamed: LED4.2 (1A), LED4.5 (3K)
unnamed: LED4.4 (2K), LED4.7 (4A)
unnamed: LED4.12 (6K), LED4.15 (8A)
unnamed: LED4.10 (5A), LED4.13 (7K)
unnamed: LED4.8 (4K), R13.2
unnamed: LED4.9 (5K), R14.2
unnamed: LED4.1 (1K), R15.2
unnamed: LED4.16 (8K), R16.2
unnamed: LED5.2 (1A), LED5.5 (3K)
unnamed: LED5.4 (2K), LED5.7 (4A)
unnamed: LED5.12 (6K), LED5.15 (8A)
unnamed: LED5.10 (5A), LED5.13 (7K)
unnamed: LED5.8 (4K), R17.2
unnamed: LED5.9 (5K), R18.2
unnamed: LED5.1 (1K), R19.2
unnamed: LED5.16 (8K), R20.2
unnamed: LED6.2 (1A), LED6.5 (3K)
unnamed: LED6.4 (2K), LED6.7 (4A)
unnamed: LED6.12 (6K), LED6.15 (8A)
unnamed: LED6.10 (5A), LED6.13 (7K)
unnamed: LED6.8 (4K), R21.2
unnamed: LED6.9 (5K), R22.2
unnamed: LED6.1 (1K), R23.2
unnamed: LED6.16 (8K), R24.2
unnamed: LED7.2 (1A), LED7.5 (3K)
unnamed: LED7.4 (2K), LED7.7 (4A)
unnamed: LED7.12 (6K), LED7.15 (8A)
unnamed: LED7.10 (5A), LED7.13 (7K)
unnamed: LED7.8 (4K), R25.2
unnamed: LED7.9 (5K), R26.2
unnamed: LED7.1 (1K), R27.2
unnamed: LED7.16 (8K), R28.2

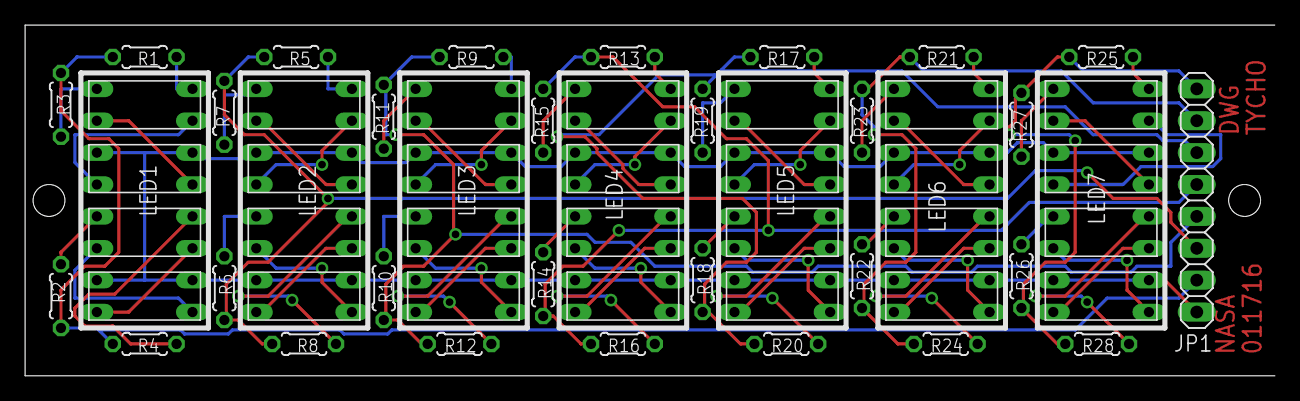
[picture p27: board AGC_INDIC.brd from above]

Board: 2 copper layers, 99.6 x 27.9 mm, 36 parts (0 on the bottom side), 64 nets.

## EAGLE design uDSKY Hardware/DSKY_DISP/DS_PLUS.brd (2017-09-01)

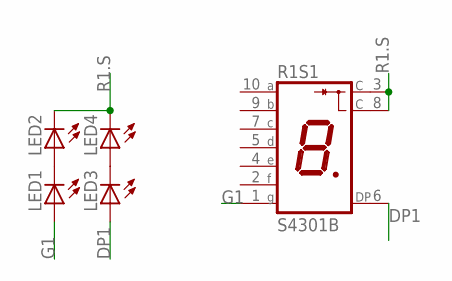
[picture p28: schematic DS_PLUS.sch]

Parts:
LED1, LED2, LED3, LED4: LEDCHIP-LED0603; CHIP-LED0603
R1S1: S4301B

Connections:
DP1: LED3.A, R1S1.6 (DP)
G1: LED1.A, R1S1.1 (G)
unnamed: LED1.C, LED2.A
unnamed: LED3.C, LED4.A
R1.S: LED2.C, LED4.C, R1S1.3 (C), R1S1.8 (C)

Board: 2 copper layers, 5 parts (0 on the bottom side), 5 nets, no tracks yet.

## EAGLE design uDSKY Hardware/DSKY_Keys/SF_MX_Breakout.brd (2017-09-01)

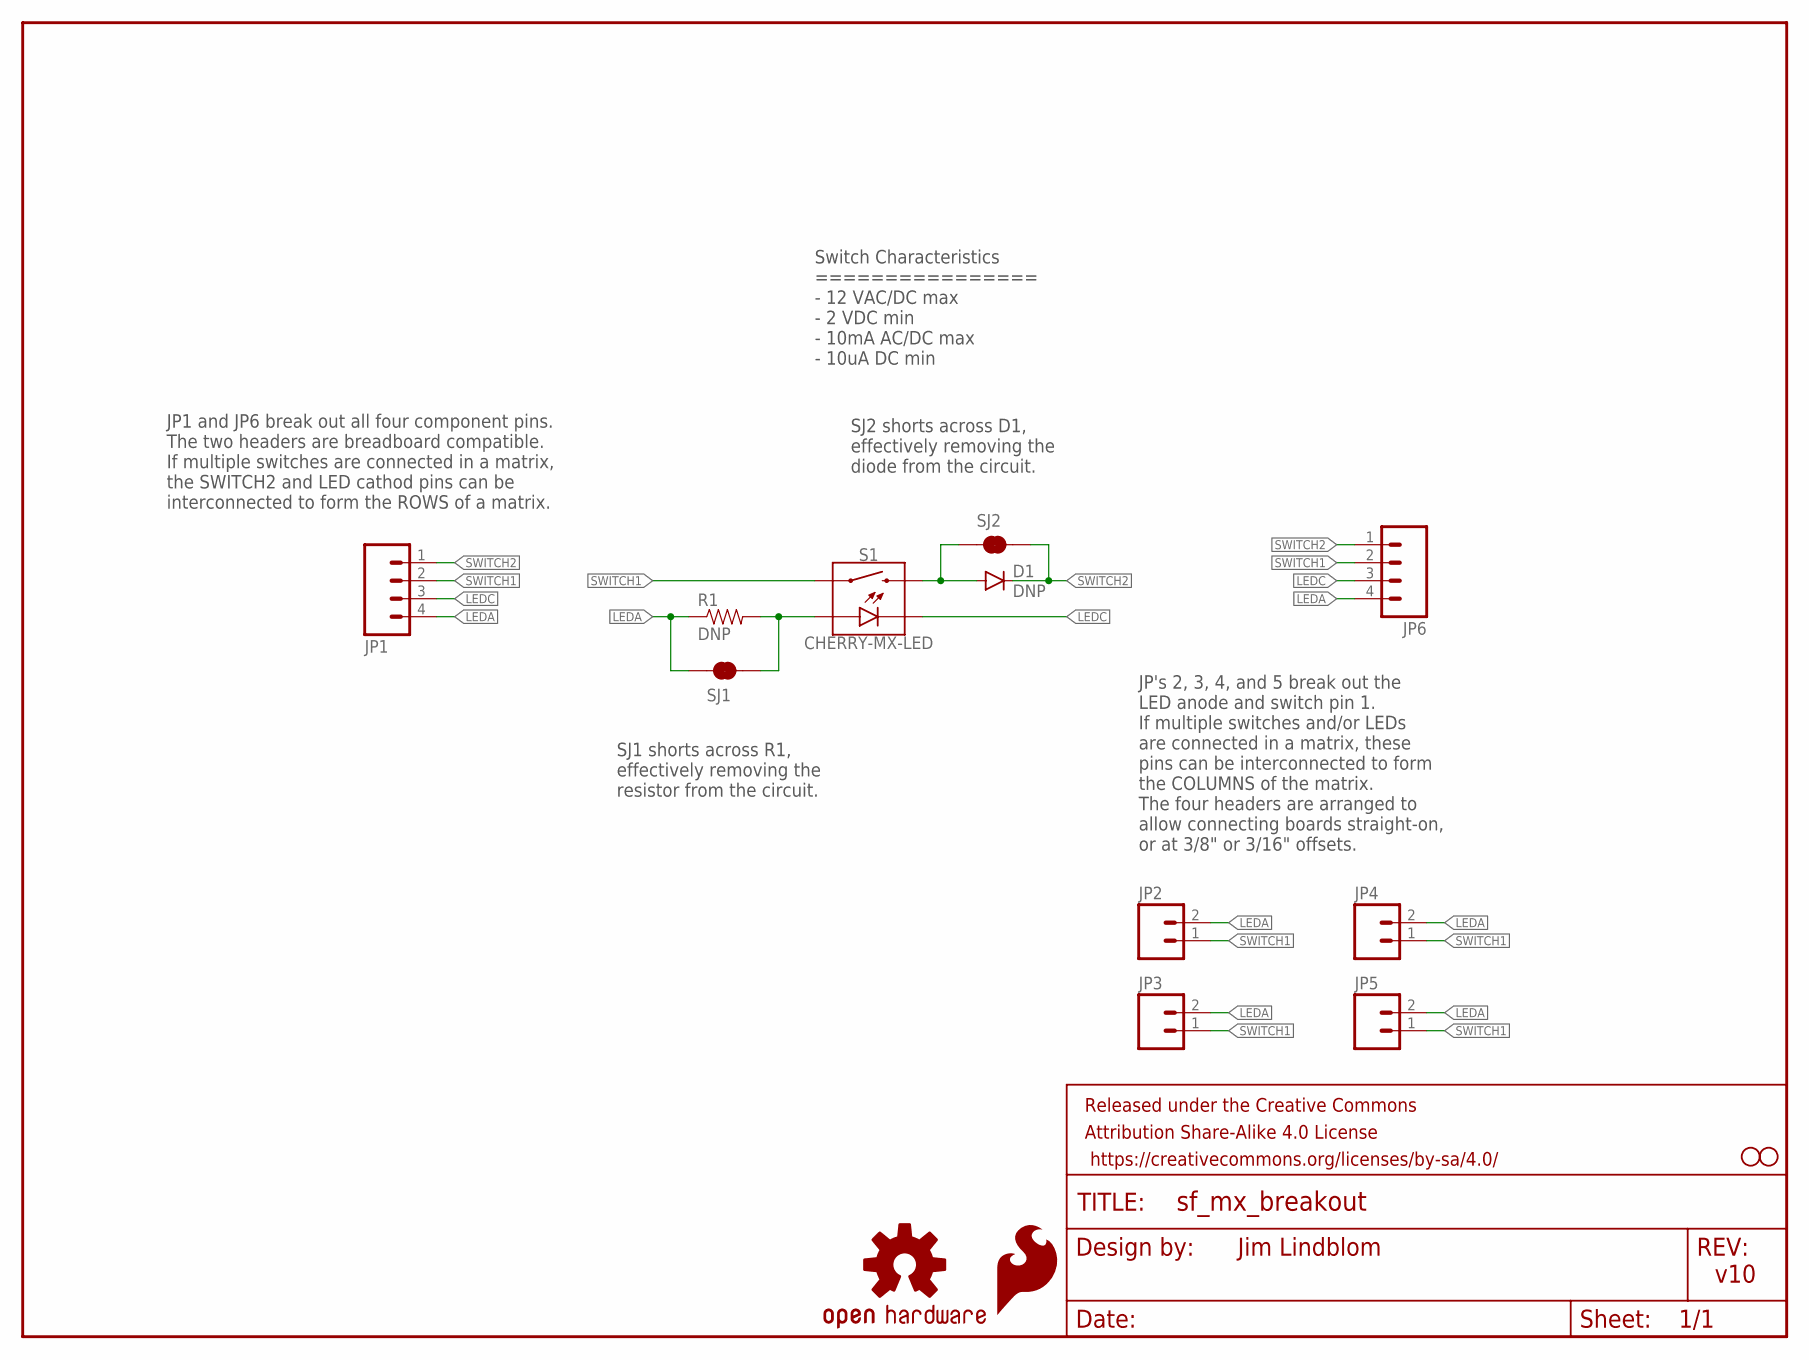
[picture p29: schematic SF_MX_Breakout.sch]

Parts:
D1: DNP; DIODE-PTH-0.1
FRAME1: FRAME-LETTER; CREATIVE_COMMONS
JP1, JP6: M04NO_SILK_ALL_ROUND; 1X04_NO_SILK_ALL_ROUND
JP2, JP3, JP4, JP5: M021X02_NO_SILK; 1X02_NO_SILK
LOGO1: OSHW-LOGOS; OSHW-LOGO-S
LOGO2: SFE_LOGO_FLAME.1_INCH; SFE_LOGO_FLAME_.1
R1: DNP; AXIAL-0.1
S1: CHERRY-MX-LED
SJ1, SJ2: JUMPER-PAD-2-NC_BY_TRACENO_SILK; PAD-JUMPER-2-NC_BY_TRACE_NO_SILK
STANDOFF1, STANDOFF2: STAND-OFF2-56; STAND-OFF-2-56

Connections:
LEDA: JP1.4, JP2.2, JP3.2, JP4.2, JP5.2, JP6.4, R1.P$1 (1), SJ1.1
LEDC: JP1.3, JP6.3, S1.K (C)
unnamed: R1.P$2 (2), S1.A, SJ1.2
unnamed: D1.A, S1.S2, SJ2.1
SWITCH1: JP1.2, JP2.1, JP3.1, JP4.1, JP5.1, JP6.2, S1.S1
SWITCH2: D1.C, JP1.1, JP6.1, SJ2.2

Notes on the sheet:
v10
Jim Lindblom
SJ1 shorts across R1, effectively removing the resistor from the circuit.
SJ2 shorts across D1, effectively removing the diode from the circuit.
JP's 2, 3, 4, and 5 break out the LED anode and switch pin 1. If multiple switches and/or LEDs are connected in a matrix, these pins can be interconnected to form the COLUMNS of the matrix. The four headers are arranged to allow connecting boards straight-on, or at 3/8" or 3/16" offsets.
JP1 and JP6 break out all four component pins. The two headers are breadboard compatible. If multiple switches are connected in a matrix, the SWITCH2 and LED cathod pins can be interconnected to form the ROWS of a matrix.
Switch Characteristics ================ - 12 VAC/DC max - 2 VDC min - 10mA AC/DC max - 10uA DC min



Board: 2 copper layers, 19.1 x 19.1 mm, 16 parts (4 on the bottom side), 6 nets.

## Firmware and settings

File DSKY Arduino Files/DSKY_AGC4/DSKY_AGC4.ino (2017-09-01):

#include <Key.h>
#include <Keypad.h>

/* This program is the DSKY for AGC4
//1. reads seral lines into buffer
//2. parses Verb, Noun, Prog, R1, r2, r3
//3. put parsed values into DSKY Displays
//4. Caution and Warning Lights. 
//5. Flash C & W Lamps
//6. Flash N V Displays
//7. SET/RESET COMP ACTY Lamp
//8. Keypad as keyboard 
    *CAUTION* writes to open screen on PC!!
    *NOTE*: Set TOOLS>USB Type>Serial+Keyboard,,,

*/

#include <string>
#include "LedControl.h"

// Create an IntervalTimer object 
IntervalTimer DSKYTimer;

//DSKY 
const byte ROWS = 3; //3 rows
const byte COLS = 7; //seven columns
char keys[ROWS][COLS] = {
  {'*','0','1','2','3','K','R'},
  {'N','-','4','5','6','P','E'},
  {'V','+','7','8','9','C','#'},
  };
byte rowPins[ROWS] = {21, 22, 23}; //connect to the row pinouts of the keypad
byte colPins[COLS] = {0, 1, 3, 4, 8, 9, 10}; //connect to the column pinouts of the keypad
  
Keypad keypad = Keypad( makeKeymap(keys), rowPins, colPins, ROWS, COLS );

/* 
 * This is in Global maybe dsky.h
 */
static char Verb[3];
static char Noun[3];
static char Prog[3];
static char R[3][6];
static char W[6];
static char C[6];


/*
Pins for teensey 3.0 on miniDSKY
 pin 17 is connected to the DataIn 
 pin 16 is connected to the CLK 
 pin 15 is connected to LOAD
 miniDSKY has 3  MAX72XX.
 */

LedControl dsky=LedControl(17, 16, 15, 3);

/* we always wait a bit between updates of the display */
unsigned long delaytime=250;
const int led = LED_BUILTIN;

int readline(int readch, char *buffer, int len)
{
  static int pos = 0;
  int rpos;

  if (readch > 0) {
    switch (readch) {
      case '\n': // Ignore new-lines
        break;
   
      case '\r': // Return on CR
        rpos = pos;
        pos = 0;  // Reset position index ready for next time
        return rpos;
      default:
        if (pos < len-1) {
          buffer[pos++] = readch;
          buffer[pos] = 0;
        }
    }
  }
  // No end of line has been found, so return -1.
  return -1;
}

void clearall(){
      dsky.clearDisplay(0);
      dsky.clearDisplay(1);
      dsky.clearDisplay(2); 
}

void ClearDisp() {
      for(int i=0;i<2;i++) {
        Verb[i]=' ';
        Noun[i]=' ';
        Prog[i]=' ';
      }
    for(int i=0;i<6;i++) {
     
    R[0][i]=' '; 
    R[1][i]=' '; 
    R[2][i]=' '; 
     }
}

void DSKY_VN(bool Blinking){
  
   dsky.setChar(2,7,Prog[0],false);
   dsky.setChar(2,6,Prog[1],false);

if(Verb[2]=='*'){
if(Blinking){
  dsky.setChar(0,7,Verb[0],false);
  dsky.setChar(0,6,Verb[1],false);
   }
else{
   dsky.setChar(0,7,' ',false);
   dsky.setChar(0,6,' ',false);
   }
}
else{
   dsky.setChar(0,7,Verb[0],false);
   dsky.setChar(0,6,Verb[1],false);

}

if(Noun[2]=='*'){
if(Blinking){
  dsky.setChar(1,7,Noun[0],false);
   dsky.setChar(1,6,Noun[1],false); 
   }
else{
   dsky.setChar(1,7,' ',false);
   dsky.setChar(1,6,' ',false);
   }
}
else{
   dsky.setChar(1,7,Noun[0],false);
   dsky.setChar(1,6,Noun[1],false);

}

}

void DSKY_R(bool Blink){
//show R1, R2, and R3

    for (int i = 0; i < 3; ++i)
    {
bool dp = false;

          for (int j = 0; j < 6; ++j) {

           dp = false;
        if (i == 1) {
          if (W[j] == '1') dp = true;
          if (W[j] == '*') dp = Blink; 
          if (W[j] == '+') dp = Blink;       
   
        }
        if (i == 2) {    
          if (C[j] == '1') dp = true;
          if (C[j] == '*') dp = Blink; 
          if (C[j] == '+') dp = Blink; 
        }
            
          dsky.setChar(i,j,R[i][5-j],dp);

          } //All 5 digits & Sign

    } //All 3 REG done
}
void setup()
{
  DSKYTimer.begin(blinkLED, 100000);  // blinkLED to run every 0.1 seconds

  pinMode(led, OUTPUT);
  Serial.begin(9600);
    /*
   The MAX72XX is in power-saving mode on startup,
   we have to do a wakeup call
   */
   
   ///////////////////////////
  // LED REG1 setup:
  //////////////////////////  
  dsky.shutdown(0,false);
  /* Set the brightness to a medium values */
  dsky.setIntensity(0,4);
  /* and clear the display */
  dsky.clearDisplay(0);
  
   ///////////////////////////
  // LED REG2 setup:
  //////////////////////////
  dsky.shutdown(1,false);
  /* Set the brightness to a medium values */
  dsky.setIntensity(1,4);
  /* and clear the display */
  dsky.clearDisplay(1);

  ///////////////////////////
  // LED REG3 setup:
  //////////////////////////
  dsky.shutdown(2,false);
  /* Set the brightness to a medium values */
  dsky.setIntensity(2,4);
  /* and clear the display */
  dsky.clearDisplay(2);

  
  ClearDisp();  
  
 
}
// The interrupt will blink the LED, and keep
// track of how many times it has blinked.
volatile bool ledState = false;
volatile unsigned long blinkCount = 0; // use volatile for shared variables



void blinkLED(void) {
/*  
  if (ledState == LOW) {
    ledState = HIGH;
    blinkCount = blinkCount + 1;  // increase when LED turns on
  } else {
    ledState = LOW;
  }
  digitalWrite(led, ledState);
*/

 blinkCount = blinkCount + 1;  // increase when LED turns on

 if (blinkCount < 4)  {   
 ledState = false;
 }
 
 else {
   ledState = true;
   if (blinkCount > 9) blinkCount = 0;
  }
//  digitalWrite(led, ledState);
}

  



void loop(){

static int indx;
static char buffer[80];

 // digitalWrite(led, ledState);
//Display on LEDs...
 delay(10);
  noInterrupts();

 DSKY_VN(ledState);  
 DSKY_R(ledState);

  interrupts();
  
   
char key = keypad.getKey();
  if (key) {


 //This is debug output of DSKY Keys:   
    Serial.println(key);
    
  //this lets the DSKY Keys control if using com porton PC   
  //if (key== 'E') Keyboard.print(key); //E does not  <enter>
   // else 
    
    Keyboard.print(key);
   
  }

  //Cebug shows status of the various displays sent
  if (readline(Serial.read(), buffer, 80) > 0) {
    Serial.print("You entered: >");
    Serial.print(buffer);
    Serial.println("<");


  /********PARSE AGC Commands*************
   * 
   * parse the serial stream state machine..
   *   v10f/n (1 =MSB 0 =LSB f = '*' = Flash) 
   *   n10f/n
   *   p10/n
   *  Rxs/n x= (1 -> 3)s= + - or Blank)
   *  Wnx/n  (n = LED# (1 -> 5)  x = 1(on) 0(0ff) *(Flash)
   *  Cnx/n  (n = LED# (1 -> 5)  x = 1(on) 0(0ff) *(Flash)
   ***************************************/

 switch(buffer[0])
    {
      case 'A':
      case 'a':
      if (buffer[1]=='0') digitalWrite(led, LOW);
      if (buffer[1]=='1') digitalWrite(led, HIGH);
      
      break;
      
      case 'V':
      case 'v':
      Verb[2] = buffer[3];   //Flash it = '*'
      Verb[1] = buffer[2];  //LSB
      Verb[0] = buffer[1];  //MSB
      break;
      
      case 'N':
      case 'n':
      Noun[2] = buffer[3];     
      Noun[1] = buffer[2];
      Noun[0] = buffer[1];
      break;
      
      case 'P':
      case 'p':
      Prog[1] = buffer[2];
      Prog[0] = buffer[1];
      break;
    /////////////////////////////////////////////  
   /*WARNING (Yellow) ndicators:
     W1 = TEMP
     W2 = GYMBAL LOCK
     W3 = PROG
     W4 = RESTART
     W5 = TRACKER
    */
      case 'W':  
      case 'w':
 //     case 'K':     //this is for DSKY K key tocontrol Warnings
         indx=6;
          if(buffer[1]=='1') indx=0;
          if(buffer[1]=='2') indx=1;
          if(buffer[1]=='3') indx=2;
          if(buffer[1]=='4') indx=3;
          if(buffer[1]=='5') indx=4;
          
        W[indx] = buffer[2];
          break;
          
    /////////////////////////////////////////////  
   /*CAUTION Indicators:
     C1 = UPLINK ACTY
     C2 = NO ATT
     C3 = STBY
     C4 = KEY REL
     C5 = OPR ERR
    */
      case 'C':              
      case 'c':
          indx=6;
          if(buffer[1]=='1') indx=0;
          if(buffer[1]=='2') indx=1;
          if(buffer[1]=='3') indx=2;
          if(buffer[1]=='4') indx=3;
          if(buffer[1]=='5') indx=4;
        C[indx] = buffer[2];
          break; 

//REGISTERS (R1, R2 , or R3)
      case 'r':
      case 'R':
          for(int i = 0; i <6; ++i){
          if(buffer[1]=='1') indx=0;
          if(buffer[1]=='2') indx=1;
          if(buffer[1]=='3') indx=2;

          R[indx][i] = buffer[i+2]; 
 
          }

      break;

        
    
    } 
/*
  //outputs for debug on serial...
 //Display on LEDs...

   dsky.setChar(0,7,Verb[0],false);
   dsky.setChar(0,6,Verb[1],false); 

   dsky.setChar(1,7,Noun[0],false);
   dsky.setChar(1,6,Noun[1],false); 

   dsky.setChar(2,7,Prog[0],false);
   dsky.setChar(2,6,Prog[1],false);

   //show R1, R2, and R3
    for (int i = 0; i < 3; ++i)
    {
//bool dp =false;
          for (int j = 0; j < 6; ++j) {
// set LEDs for positive sign ( SEG G + dp)case:
           if( R[i][5-j] == '+') {
                      dsky.setChar(i,j,'-',true);
                      break;
           }
          dsky.setChar(i,j,R[i][5-j],false);

          }

    } 
 */   
  //Show master mode Program PROG
     Serial.print("P: [");
     Serial.print(Prog[0]);
     Serial.print("] [");  

     Serial.print(Prog[1]);
     Serial.println("]  ");  
 //Show Verb    
    Serial.print("V: [");
    Serial.print(Verb[0]);
    Serial.print("] [");
    Serial.print(Verb[1]); 
    Serial.print("]  "); 
 //Show Noun   
    Serial.print("N: [");
    Serial.print(Noun[0]);
    Serial.print("] [");
    Serial.print(Noun[1]);
    Serial.println("]  "); 

//show R1, R2, and R3
    for (int i = 0; i < 3; ++i)
    {
          Serial.print("R[");
          Serial.print(i+1);
          Serial.print("]= ");      
          for (int j = 0; j < 6; ++j) {
            Serial.print("[");
            Serial.print(R[i][j]);

            Serial.print("] ");
          }
            Serial.println(" "); 
    } 
//Print LEDs
          Serial.print("W = ");
          for (int i = 0; i < 5; ++i) {
            Serial.print(i+1);
            Serial.print("[");
            Serial.print(W[i]);
            Serial.print("] ");  
          }
            Serial.println(" "); 
 
           Serial.print("C = ");
          for (int i = 0; i < 5; ++i) {
            Serial.print(i+1);
            Serial.print("[");
            Serial.print(C[i]);
            Serial.print("] ");  
          }
            Serial.println(" ");  


 //Display on LEDs...

/*
//show R1, R2, and R3
    for (int i = 0; i < 3; ++i)
    {
bool dp = false;

          for (int j = 0; j < 6; ++j) {

           dp = false;
        if (i == 1) {
          if (W[j] == '1') dp = true;
          if (W[j] == '*') dp = ledState; 
   
        }
        if (i == 2) {    
          if (C[j] == '1') dp = true;
          if (C[j] == '*') dp = ledState; 
    
        }
            
          dsky.setChar(i,j,R[i][5-j],dp);

          } //All 5 digits & Sign

    } //All 3 REG done
*/
    }    

  }

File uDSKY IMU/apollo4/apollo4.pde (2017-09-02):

/**
 * Apollo4 
 * by Steve Botts
 * 
 * 3D model used for visulization 
 * of INS roll , pitch and yaw angles. 
 * Command Module is a compound closed cylinder
 * Service Module is a closed Cylinder
 * Nozzel is a compound open cylinder (with no top or bottom)
 * mouse controls ROLL and YAW angle only to inspect model
 */
/**
 * Apollo Spacecraft. 
 * asm texture = asm01,jpg
 * . 
 */
 
int tubeRes = 100;
float[] tubeX = new float[tubeRes];
float[] tubeY = new float[tubeRes];
PImage SMimg;
PImage CMimg;
float dz =0;
float ZZ=0;
void setup() {
  size(720, 640, P3D);
  SMimg = loadImage("asm02.png");
  CMimg = loadImage("CM2d.JPG");
  
  float angle = 360.0 / tubeRes;
  for (int i = 0; i < tubeRes; ++i) {
    tubeX[i] = cos(radians(i * angle));
    tubeY[i] = sin(radians(i * angle));
  }
  noStroke();
  println(SMimg.width);
  println(SMimg.height);
}

void draw() {
  background(0);
  fill(0, 255, 0); //green numbers
  
 text("YAW = " + (mouseX), 0, 10, 0);
 text("ROLL = " + (mouseY), 0, 25, 0);
 text("DZ = " + dz, 0, 35, 0);
 //DSKY Display
 text("DSKY:", width-60, 10, 0);
 text("        00", width-60, 20, 0);  //prog 00
 text("16    65", width-60, 30, 0); // V16 N65
 text("=====", width-60, 40, 0);
 
 if (hour()<10) {
  text("+0000"+ hour(), width-60, 50, 0);  
 } else
 text("+000"+ hour(),width-60, 50, 0);
 
  if (minute()<10) {
  text("+0000"+ minute(), width-60, 60, 0);  
 } else
 text("+000"+ minute(), width-60, 60, 0);
 
  if (second()<10) {
  text("+0"+ second()+"000", width-60, 70, 0);  
 } else 
 text("+"+ second()+"000", width-60, 70, 0); 
 
 // text("+"+ second()+ "0"+ millis(), width-60, 60, 0);

 lights();
 directionalLight(255, 255, 255, 0, -1, 0);

  translate(width / 2, height / 2);

  rotateX(map(mouseY*1.5, 0, width, 0, PI));
  rotateZ(map(mouseX*1.5+dz, 0, height, 0, -PI));
 ZZ +=dz;
 //  rotateZ(map(mouseX*1.5+ZZ, 0, height, 0, -PI));
  rotateY(map(ZZ, 0, width, 0, PI));
  
  translate(0, -50, 0);
  
   //red z axis antenna
   stroke(255,0,0);
  strokeWeight(4);
  line(0,0,-103,0,0,103); 
  
  //blue y axis antenna
  stroke(0,0,255);
  strokeWeight(4);
  line(0,-135,0,0,0,0); 
  
  
    //green x axis antenna
   stroke(0,255,0);
  strokeWeight(4);
  line(103,0,0,-103,0,0); 

  translate(0, 50, 0);
  /*
  APOLLO SPACECRAFT MODEL
  */
 //Aft HIGH GAIN  antenna's mast
   stroke(155,155,155);
   strokeWeight(6);
   line(70,50,120,0,50,0); //Draw antenna mast

  //Draw Service Module (SM) 
   noStroke();  //draw solid shapes...
   //fill(205, 205, 205); //Aluminum Grey
   fill(66, 66, 66); //Aluminum Grey
      
   translate(0, -150, 0);
   
      drawTube(99.9,99.9, 200, 200); // Draw the service module (SM)
         translate(0, 100, 0);
         
      drawASM();  //wrap the details on the Service Module
 /****************************************************************** 
//Draw Command Module (CM) 
*******************************************************************/

   fill(188,188,188);  //bright color
   translate(0, -199, 0); 
   drawCylinder(21*1.5, 66*1.5, 70*1.5, 180); // Draw the command module (CM)
   
   translate(0, 65*1.5, 0);
   drawACM();
   translate(0, -65*1.5, 0); 
   
    translate(0, -7, 0);  
  //fill(220, 220, 220); //grey color
    fill(255, 215, 0); // gold color
    drawTube(15, 15, 8, 100);//draw LM docking tunnel
    fill(255, 0, 0); // red color 
      drawTube(16, 16, 2, 100);//draw LM docking target
      drawTube(14, 14, 1, 100);      
    translate(0, -8, 0); 
       fill(222, 222, 222); //grey color 
//    noFill();
//    stroke(255, 210, 0);
//    drawTube(3, 8, 16, 6); //draw LM docking probe  
    drawTube(0, 10, 20, 20); //draw LM docking probe  
    translate(0, 10, 0);  
//    noStroke(); 


//Draw Service Propulsion System (SPS) Main Engine 
    translate(0, 300, 0); //Move AFT
    fill(220, 220, 212); //grey color 
    drawCap(100,0,24);
    
 //SPS engine heatshield   
    fill(180, 180, 180);
//  fill(255, 215, 0); // gold color looks like foil?
    drawCylinder(69*1.2, 52*1.2, 33*1.2, 9); // Draw the SPS engine's heatshield
    translate(0, 35, 0);
    
//SPS Nozzle       
  fill(62, 50, 50);
    
    drawTube(20, 40, 60, 13); // Draw the upper SPS engine's nozzle
    translate(0, 60, 0); //Move AFT     
  
    fill(72, 70, 80);
    drawTube(40, 60, 60, 13); // Draw the lower SPS engine's nozzle
    
//High gain antenna
   fill(255, 215, 0); // gold color 
   translate(67, -85, 115);
   drawTube(3, 24, 9, 8); //draw HIGH GAIN antenna dish
     //HIGH GAIN Antenna's feedhorn
    stroke(255, 215, 0); //Gold 
    strokeWeight(2);
    line(0,-10,0,0,24,0);  //Draw antenna feedhorn 

}

/******************************************************
*  Shape Drawing functions
******************************************************/

void drawCylinder(float topRadius, float bottomRadius, float tall, int sides) {
  float angle = 0;
  float angleIncrement = TWO_PI / sides;
  beginShape(QUAD_STRIP);
    texture(SMimg);
  for (int i = 0; i < sides + 1; ++i) {
    vertex(topRadius*cos(angle), 0, topRadius*sin(angle));
    vertex(bottomRadius*cos(angle), tall, bottomRadius*sin(angle));
    angle += angleIncrement;
  }
  endShape();
  
  // If it is not a cone, draw the circular top cap
  if (topRadius != 0) {
    angle = 0;
    beginShape(TRIANGLE_FAN);
    
    // Center point
    vertex(0, 0, 0);
    for (int i = 0; i < sides + 1; i++) {
      vertex(topRadius * cos(angle), 0, topRadius * sin(angle));
      angle += angleIncrement;
    }
    endShape();
  }

  // If it is not a cone, draw the circular bottom cap
  if (bottomRadius != 0) {
    angle = 0;
    beginShape(TRIANGLE_FAN);

    // Center point
    vertex(0, tall, 0);
    for (int i = 0; i < sides + 1; i++) {
      vertex(bottomRadius * cos(angle), tall, bottomRadius * sin(angle));
      angle += angleIncrement;
    }
    endShape();
  
  }
  
  }
  
  //draw nozzle does not have endcaps!
void drawTube(float topRadius, float bottomRadius, float tall, int sides) {
  float angle = 0;
  float angleIncrement = TWO_PI / sides;
  beginShape(QUAD_STRIP);
  for (int i = 0; i < sides + 1; ++i) {
    vertex(topRadius*cos(angle), 0, topRadius*sin(angle));
    vertex(bottomRadius*cos(angle), tall, bottomRadius*sin(angle));
    angle += angleIncrement;
  }
  endShape(); 
}
void drawASM(){
 beginShape(QUAD_STRIP);
  texture(SMimg);
  for (int i = 0; i < tubeRes; ++i) {
    float x = tubeX[i] * 100;
    float z = tubeY[i] * 100;
    float u = SMimg.width / tubeRes * i;
    vertex(x, -100, z, u, 0);
    vertex(x, 100, z, u, SMimg.height);
  }
  endShape(); 
}
void drawACM(){
  // Draw CM Exterior details
  
  beginShape(QUAD_STRIP);
  texture(CMimg);
  for (int i = 0; i < tubeRes; ++i) {
    float x = tubeX[i] * 100;
    float z = tubeY[i] * 100;
    float u = CMimg.width / tubeRes * i;
    vertex(x, 0, z, u, 0);
    vertex(x*.30, -100, z*.30, u, CMimg.height);
  }
  endShape();
}
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

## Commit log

2017-09-01 Add files via upload
    Eagle Files
    [AGC_INDIC.brd, AGC_INDIC.sch, DSKY_DISP.brd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]
2017-09-02 Add files via upload
    Processing files to demonstrate 9DOF IMU - not yet part of uDSKY
2017-09-03 Update readme.txt
    Added URL for PJRC prop Shield
2020-08-09 3D printed chassis
2020-08-15 Update LED Display
    Better description of how to simulate the EL display with LEDs

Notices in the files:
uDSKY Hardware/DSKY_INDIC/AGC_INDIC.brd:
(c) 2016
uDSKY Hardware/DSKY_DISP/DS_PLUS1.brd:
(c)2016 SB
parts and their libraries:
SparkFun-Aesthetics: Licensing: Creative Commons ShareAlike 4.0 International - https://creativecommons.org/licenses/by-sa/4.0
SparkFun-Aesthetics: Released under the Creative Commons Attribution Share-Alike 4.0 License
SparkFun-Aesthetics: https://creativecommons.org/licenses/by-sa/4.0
